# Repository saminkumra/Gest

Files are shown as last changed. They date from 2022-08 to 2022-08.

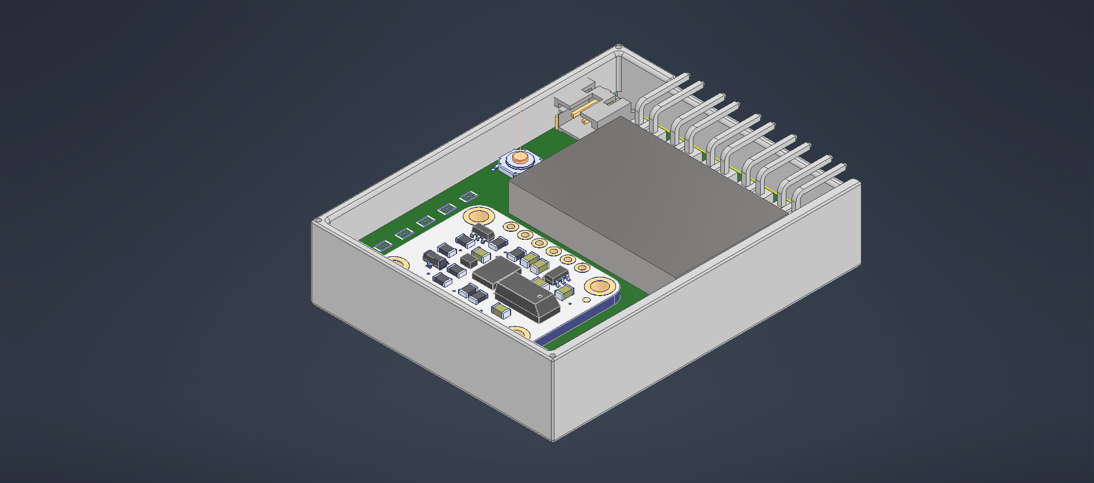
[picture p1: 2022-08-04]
hardware/3D_CAD/enclosure_1.png

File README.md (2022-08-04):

# CE347_Gest
###### By Joshua Feist, Isabelle Johnson, Samin Kumra, Seth May, Haroon Nawaz, Danche Smilkova, and Chris Uustal

### What is Gest? 
The next generation of human-computer interface devices. 

### How does it work? 
While wearing a Gest, you can connect to your laptop and perform different gestures
which then map to basic functions on your computer. 

### Is it open source? 
Yes! That's why all the code is on GitHub. 

### Update Log:
- Added BLE connectivity
	- Requires ESP32 or similar BLE-enabled microcontroller
- Added basic mouse movement support
	- Requires BNO055 sensor

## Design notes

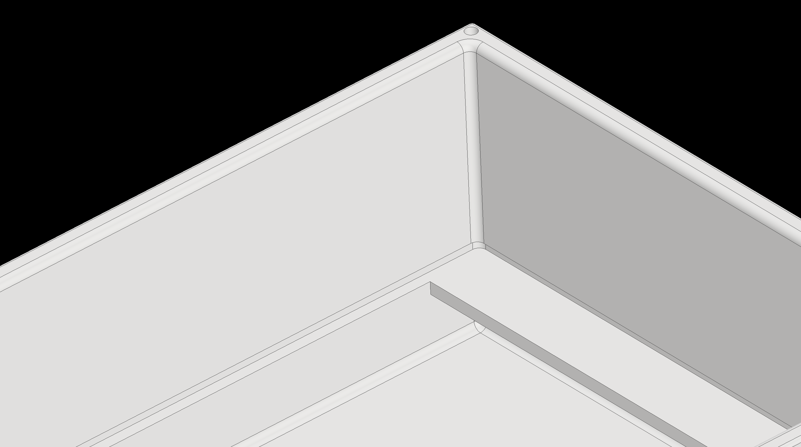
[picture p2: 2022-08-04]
hardware/3D_CAD/enclosure_corner.png

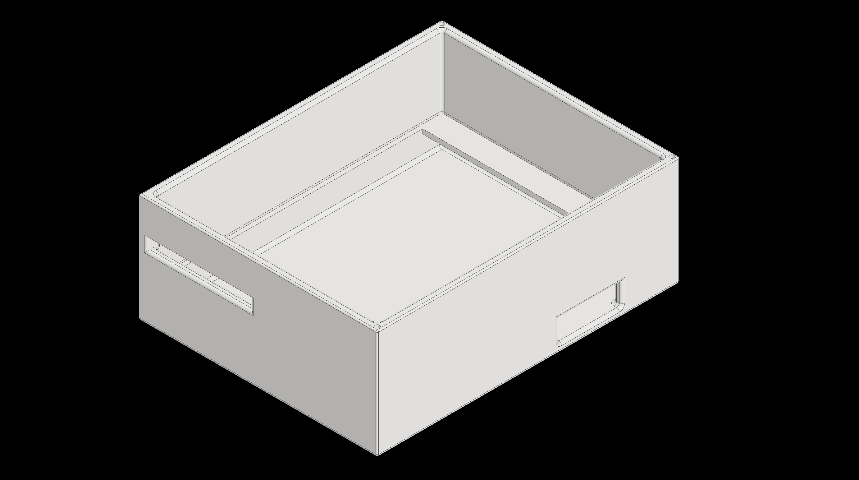
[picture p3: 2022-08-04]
hardware/3D_CAD/enclosure_2.png

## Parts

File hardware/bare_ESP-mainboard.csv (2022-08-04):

Qty | Value | Device | Package | Parts | Description | AVAILABILITY | DESCRIPTION | HEIGHT | LCSC# | MANUFACTURER_NAME | MANUFACTURER_PART_NUMBER | MF | MOUSER_PART_NUMBER | MOUSER_PRICE-STOCK | MP | MPN | OC_FARNELL | OC_NEWARK | PACKAGE | POPULARITY | PRICE | PURCHASE-URL | SPICEPREFIX
1 |  | 22-23-2061 | 22-23-2061 | X1 | .100 (2.54mm) Center Header - 6 Pin" |  |  |  |  |  |  | MOLEX |  |  |  | 22-23-2061 | 1462922 | 27C1933 |  | 6
1 | 100K | RESISTOR_0603_NOOUT | 0603-NO | R12 | Resistors
1 | 100u | CPOL-EUB/3528-21W | B/3528-21W | C4 | POLARIZED CAPACITOR, European symbol |  |  |  |  |  |  |  |  |  |  |  |  |  |  | 4 |  |  | C
3 | 10K | R-EU_R0603 | R0603 | R4, R5, R9 | RESISTOR, European symbol |  |  |  |  |  |  |  |  |  |  |  |  |  |  | 70 |  |  | R
2 | 10u | C-EUC0603 | C0603 | C3, C5 | CAPACITOR, European symbol |  |  |  |  |  |  |  |  |  |  |  |  |  |  | 73 |  |  | C
1 | 12MHz | YSX321SL | SMD3225 | Q1 | SMD Crystal Resonator |  |  |  |  |  |  | Yangxing Tech |  |  | X322512MSB4SI |  |  |  | SMD3225
3 | 15K | FLIPFLOP-RES | 0805-THM | R1, R2, R3 | Flip Flop resistor
2 | 22 | C-EUC0603 | C0603 | C1, C2 | CAPACITOR, European symbol |  |  |  |  |  |  |  |  |  |  |  |  |  |  | 73 |  |  | C
3 | 22-23-2021 | 22-23-2021 | 22-23-2021 | FLEX1, FLEX2, FLEX3 | .100 (2.54mm) Center Header - 2 Pin" |  |  |  |  |  |  | MOLEX |  |  |  | 22-23-2021 | 1462926 | 25C3832 |  | 40
5 | 470 | R-EU_R0603 | R0603 | R6, R7, R8, R10, R11 | RESISTOR, European symbol |  |  |  |  |  |  |  |  |  |  |  |  |  |  | 70 |  |  | R
2 | BC847 | BC847 | SOT23 | T1, T2 | NPN TRANSISTOR |  |  |  |  |  |  |  |  |  |  |  |  |  |  | 5
2 | BLUE | 597-5311-402F | LEDC2012X70N | D1, D2 | LED Uni-Color Green 560nm 2-Pin Chip 0805(2012Metric) Strip | Unavailable | LED Uni-Color Green 560nm 2-Pin Chip 0805_2012Metric_ Tape |  |  |  |  | Dialight |  |  | 597-5311-402F |  |  |  | 0805 Dialight |  | None
1 | CH340G | CH340G | SOIC16 | U2
1 | DIO5508XS8 | DIO5508XS8 | SOIC127P600X170-9N | IC2 | Battery Management 1A Lithium Ion Battery Charger IC |  | Battery Management 1A Lithium Ion Battery Charger IC | 1.7mm |  | DIOO Microcircuits | DIO5508XS8 |  | 453-DIO5508XS8 | https://www.mouser.co.uk/ProductDetail/DIOO-Microcircuits/DIO5508XS8?qs=wUXugUrL1qzPv8nEmpxvyA%3D%3D
1 | DMG3415U | MOSFET-P | SOT23-R | Q3 | P-Channel Mosfet
1 | ESP32-WROOM-32D | ESP32-WROOM-32D | MODULE_ESP32-WROOM-32D | U1 | Bluetooth, WiFi 802.11b/g/n, Bluetooth v4.2 + EDR, Class 1, 2 and 3 Transceiver Module 2.4GHz ~ 2.5GHz Integrated, Trace Surface Mount Check availability | In Stock | Bluetooth, WiFi 802.11b/g/n, Bluetooth v4.2 +EDR, Class 1, 2 and 3 Transceiver Module 2.4GHz ~ 2.5GHz Integrated |  |  |  |  | Espressif Systems |  |  | ESP32-WROOM-32D |  |  |  | Module Espressif Systems |  | None | https://pricing.snapeda.com/search/part/ESP32-WROOM-32D/?ref=eda
3 | GREEN | 597-5311-402F | LEDC2012X70N | D3, D5, D6 | LED Uni-Color Green 560nm 2-Pin Chip 0805(2012Metric) Strip | Unavailable | LED Uni-Color Green 560nm 2-Pin Chip 0805_2012Metric_ Tape |  |  |  |  | Dialight |  |  | 597-5311-402F |  |  |  | 0805 Dialight |  | None
1 | JSTPH | CON_JST_PH_2PIN | JSTPH2 | X2 | JST 2-Pin Right-Angle Connector
1 | MBR120 | DIODE-SCHOTTKYSOD-123 | SOD-123 | D4
1 | TPS78533QWDRBRQ1 | TPS78533QWDRBRQ1 | SON65P300X300X100-9N | IC1 | LDO Voltage Regulators Automotive, 1-A, high-accuracy, adjustable low-dropout (LDO) linear regulator |  | LDO Voltage Regulators Automotive, 1-A, high-accuracy, adjustable low-dropout (LDO) linear regulator | 1mm |  | Texas Instruments | TPS78533QWDRBRQ1 |  | 595-TPS78533QWDRBRQ1 | https://www.mouser.co.uk/ProductDetail/Texas-Instruments/TPS78533QWDRBRQ1?qs=iLbezkQI%252BsiNbdqh2Ko9GQ%3D%3D
2 | TS36CA-0.7 | TS36CA-0.7 | SMD | BTN1, BTN2 | SHOU HAN TS36CA-0.7 |  |  |  | C412365 |  |  | SHOU HAN |  |  | TS36CA-0.7
1 | USB4105_REVA | USB4105_REVA | GCT_USB4105_REVA | J1 | USB Type C Receptacle for USB 2.0 | Unavailable | USB-C (USB TYPE-C) USB 2.0 Receptacle Connector 24 (16+8 Dummy) Position Surface Mount, Right Angle | Through Hole |  |  |  |  | Global Connector Technology |  |  | USB4105 |  |  |  | Package |  | None

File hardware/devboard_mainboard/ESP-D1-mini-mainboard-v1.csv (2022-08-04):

Qty | Value | Device | Package | Parts | Description | DESCRIPTION | DIGI-KEY_PART_NUMBER | HEIGHT | MANUFACTURER_NAME | MANUFACTURER_PART_NUMBER | MF | MOUSER_PART_NUMBER | MOUSER_PRICE-STOCK | MP | MPN | OC_FARNELL | OC_NEWARK | PACKAGE | POPULARITY | PURCHASE-URL | SPICEPREFIX
1 |  | 22-23-2061 | 22-23-2061 | X1 | .100 (2.54mm) Center Header - 6 Pin" |  |  |  |  |  | MOLEX |  |  |  | 22-23-2061 | 1462922 | 27C1933 |  | 6
5 |  | LEDCHIPLED_0805 | CHIPLED_0805 | LED1, LED2, LED3, LED4, LED5 | LED
1 | 100u | CPOL-EUB/3528-21W | B/3528-21W | C4 | POLARIZED CAPACITOR, European symbol |  |  |  |  |  |  |  |  |  |  |  |  |  | 4 |  | C
2 | 10k | R-US_M0805 | M0805 | R9, R12 | RESISTOR, American symbol
1 | 10u | C-EUC0603 | C0603 | C3 | CAPACITOR, European symbol |  |  |  |  |  |  |  |  |  |  |  |  |  | 73 |  | C
3 | 15K | R-US_M0805 | M0805 | R1, R2, R3 | RESISTOR, American symbol
5 | 1k | R-US_M0805 | M0805 | R4, R5, R6, R7, R8 | RESISTOR, American symbol
3 | 22-23-2021 | 22-23-2021 | 22-23-2021 | FLEX1, FLEX2, FLEX3 | .100 (2.54mm) Center Header - 2 Pin" |  |  |  |  |  | MOLEX |  |  |  | 22-23-2021 | 1462926 | 25C3832 |  | 40
1 | 2k | R-US_M0805 | M0805 | R13 | RESISTOR, American symbol
1 | 3k | R-US_M0805 | M0805 | R14 | RESISTOR, American symbol
2 | 470 | R-EU_R0603 | R0603 | R10, R11 | RESISTOR, European symbol |  |  |  |  |  |  |  |  |  |  |  |  |  | 70 |  | R
1 | BUTTON | BUTTON | BUTTON_4_PAD | S1 | Button SPST-NO DigiKey | Tactile Switch SPST-NO Top Actuated Surface Mount | CKN9104TR-ND |  |  |  | C&K |  |  | PTS525SM15SMTR2 LFS |  |  |  | Tactile Switch CK |  | https://pricing.snapeda.com/search/part/PTS525SM15SMTR2 LFS/?ref=eda
1 | DIO5508XS8 | DIO5508XS8 | SOIC127P600X170-9N | IC2 | Battery Management 1A Lithium Ion Battery Charger IC | Battery Management 1A Lithium Ion Battery Charger IC |  | 1.7mm | DIOO Microcircuits | DIO5508XS8 |  | 453-DIO5508XS8 | https://www.mouser.co.uk/ProductDetail/DIOO-Microcircuits/DIO5508XS8?qs=wUXugUrL1qzPv8nEmpxvyA%3D%3D
2 | GREEN | LEDCHIPLED_0805 | CHIPLED_0805 | D5, D6 | LED
1 | JSTPH | CON_JST_PH_2PIN | JSTPH2 | X2 | JST 2-Pin Right-Angle Connector
1 | MH-ET_ESP32_D1_MINI | MH-ET_ESP32_D1_MINI | MH-ET_ESP32_D1_MINI | U$1
1 | TPS78533QWDRBRQ1 | TPS78533QWDRBRQ1 | SON65P300X300X100-9N | IC1 | LDO Voltage Regulators Automotive, 1-A, high-accuracy, adjustable low-dropout (LDO) linear regulator | LDO Voltage Regulators Automotive, 1-A, high-accuracy, adjustable low-dropout (LDO) linear regulator |  | 1mm | Texas Instruments | TPS78533QWDRBRQ1 |  | 595-TPS78533QWDRBRQ1 | https://www.mouser.co.uk/ProductDetail/Texas-Instruments/TPS78533QWDRBRQ1?qs=iLbezkQI%252BsiNbdqh2Ko9GQ%3D%3D

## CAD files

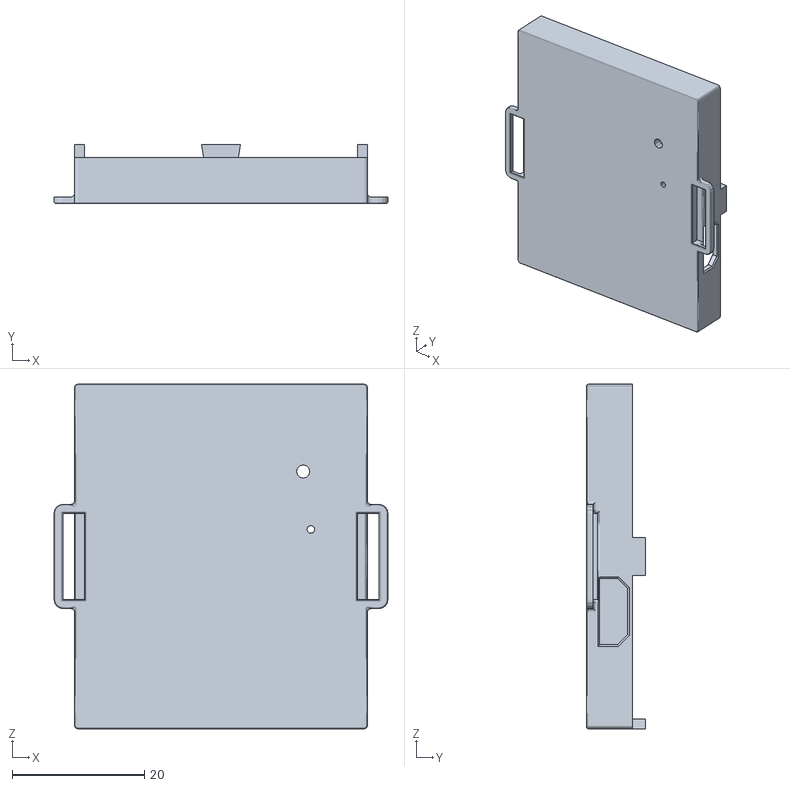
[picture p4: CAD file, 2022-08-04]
hardware/3D_CAD/enclosure5_precise.stl
50.6 x 8.95 x 52.2

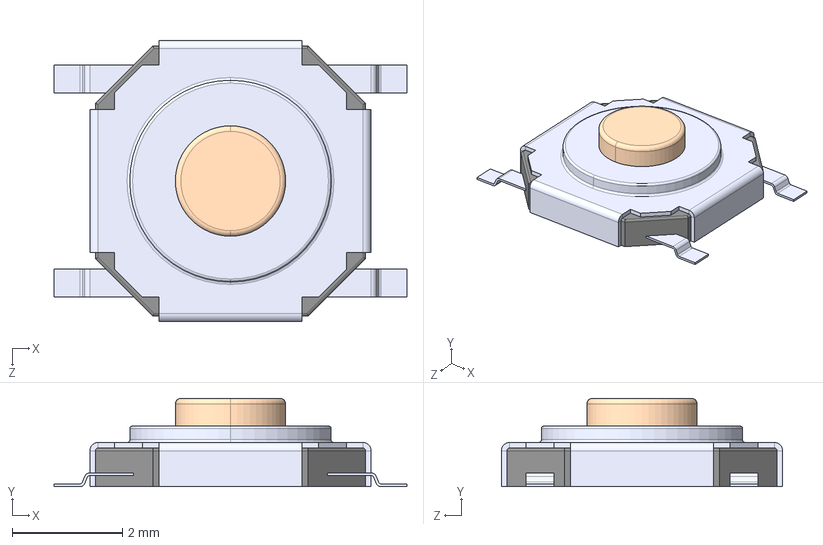
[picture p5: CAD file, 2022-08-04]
hardware/3D_CAD/PTS525SM15SMTR2 LFS.STEP
6.40 x 1.60 x 5.10 mm

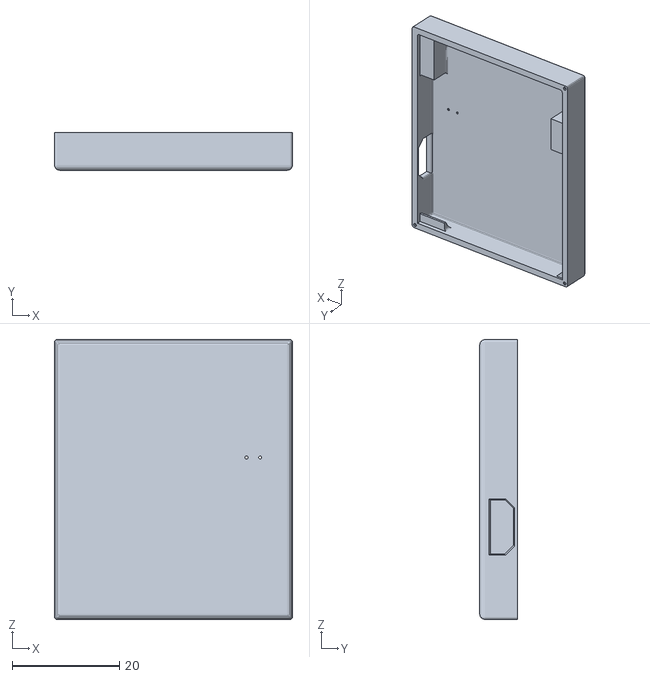
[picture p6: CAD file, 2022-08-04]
hardware/3D_CAD/enclosure3.stl
44.4 x 7.00 x 52.2

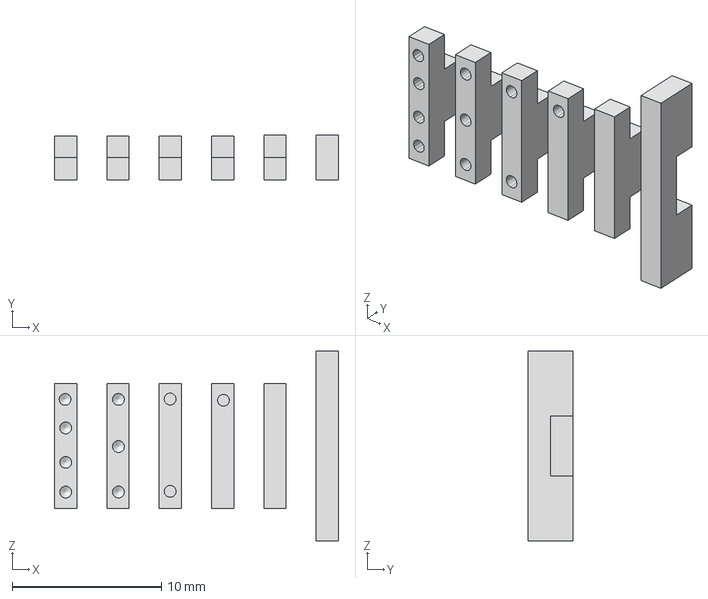
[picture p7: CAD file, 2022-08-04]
hardware/3D_CAD/press_fit_test.3mf
19.0 x 3.00 x 12.7 mm

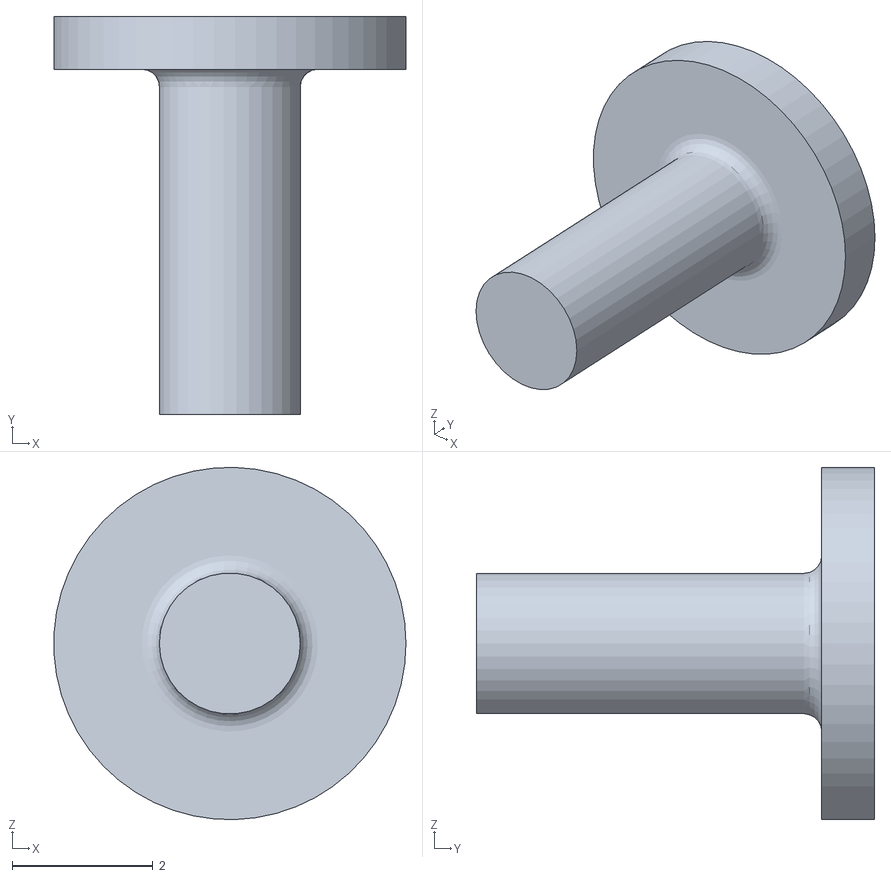
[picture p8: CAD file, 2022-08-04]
hardware/3D_CAD/enclosure3_button.stl
5.00 x 5.65 x 5.00

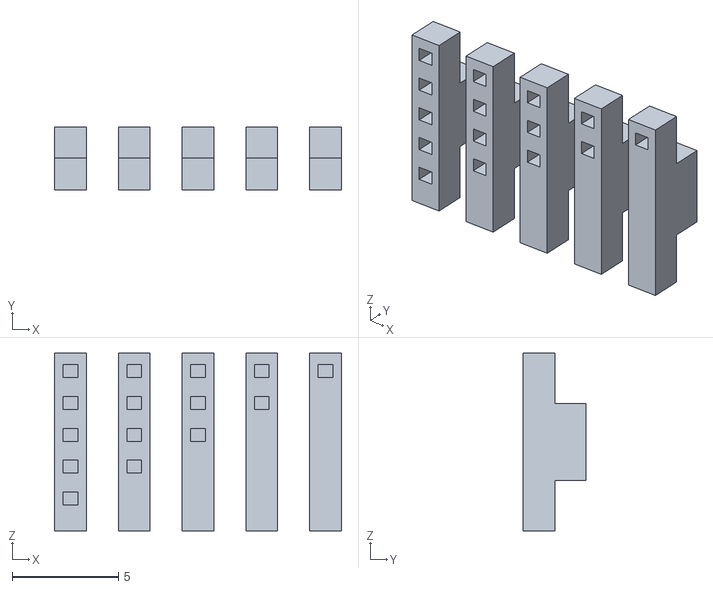
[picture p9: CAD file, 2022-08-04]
hardware/3D_CAD/press_fit_test_2.stl
13.5 x 2.95 x 8.35

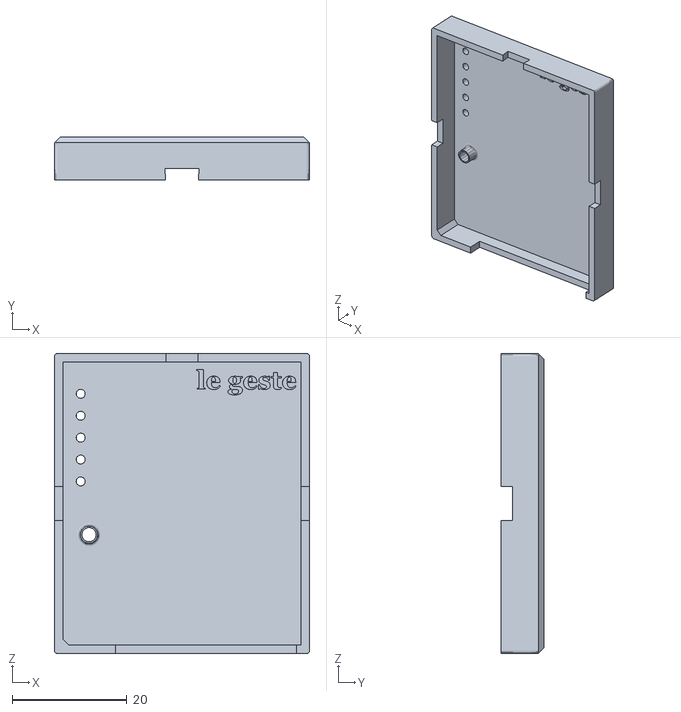
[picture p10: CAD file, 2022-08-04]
hardware/3D_CAD/enclosure5_top_precise.stl
44.4 x 7.50 x 52.2

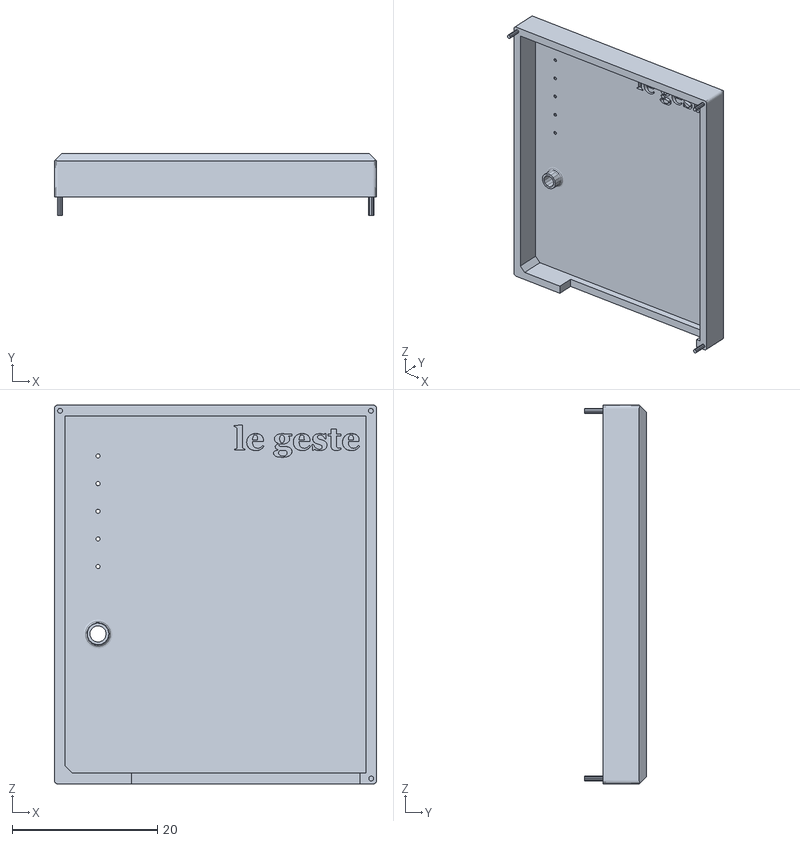
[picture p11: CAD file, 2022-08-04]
hardware/3D_CAD/enclosure3_top.stl
44.4 x 8.50 x 52.2

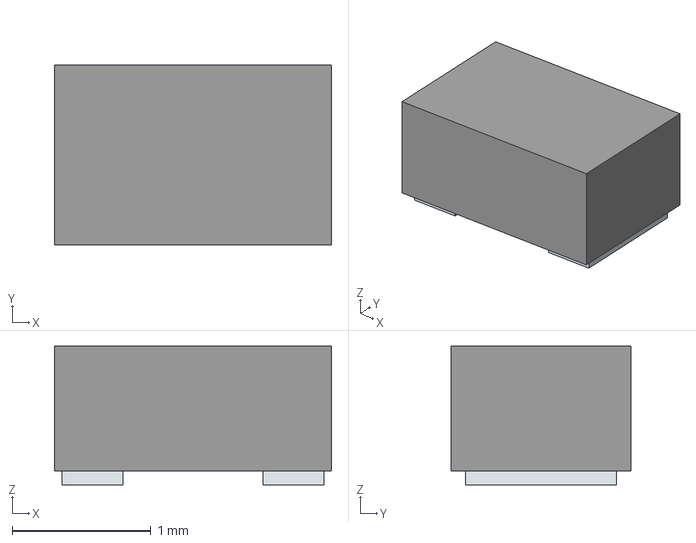
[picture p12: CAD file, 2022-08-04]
hardware/3D_CAD/LG_R971-KN-1-0-20-R18.stp
2.00 x 1.30 x 1.00 mm
Pins

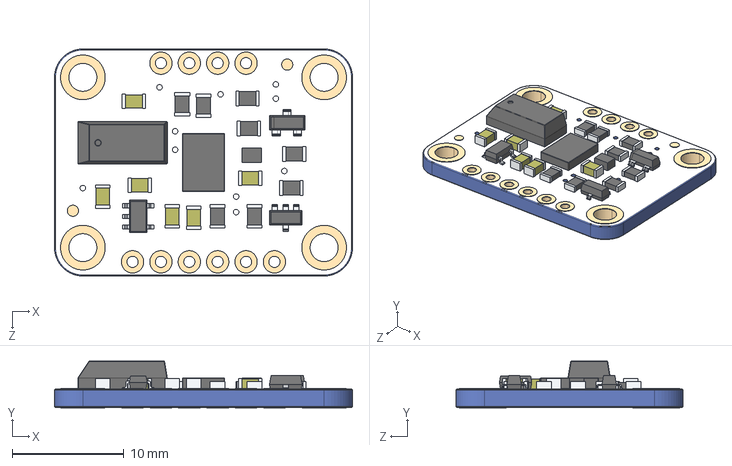
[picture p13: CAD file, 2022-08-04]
hardware/3D_CAD/Adafruit_BNO055_AP214.STEP
26.7 x 4.20 x 20.3 mm

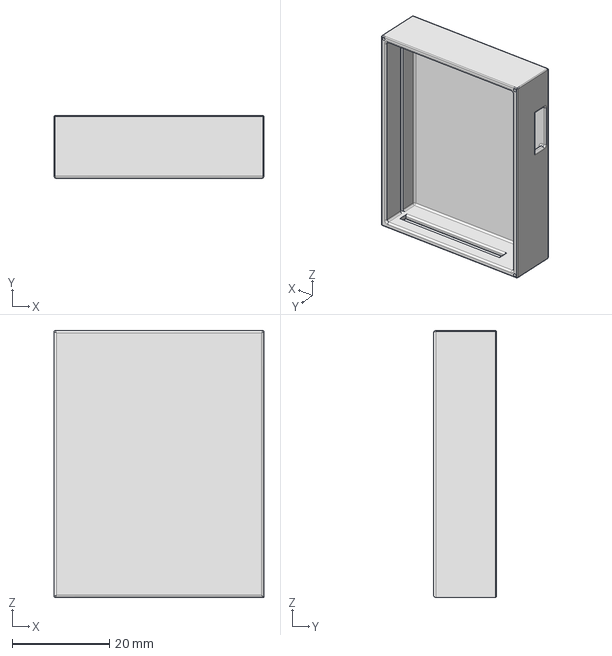
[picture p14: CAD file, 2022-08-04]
hardware/3D_CAD/enclosure2.stp
43.3 x 13.0 x 55.0 mm

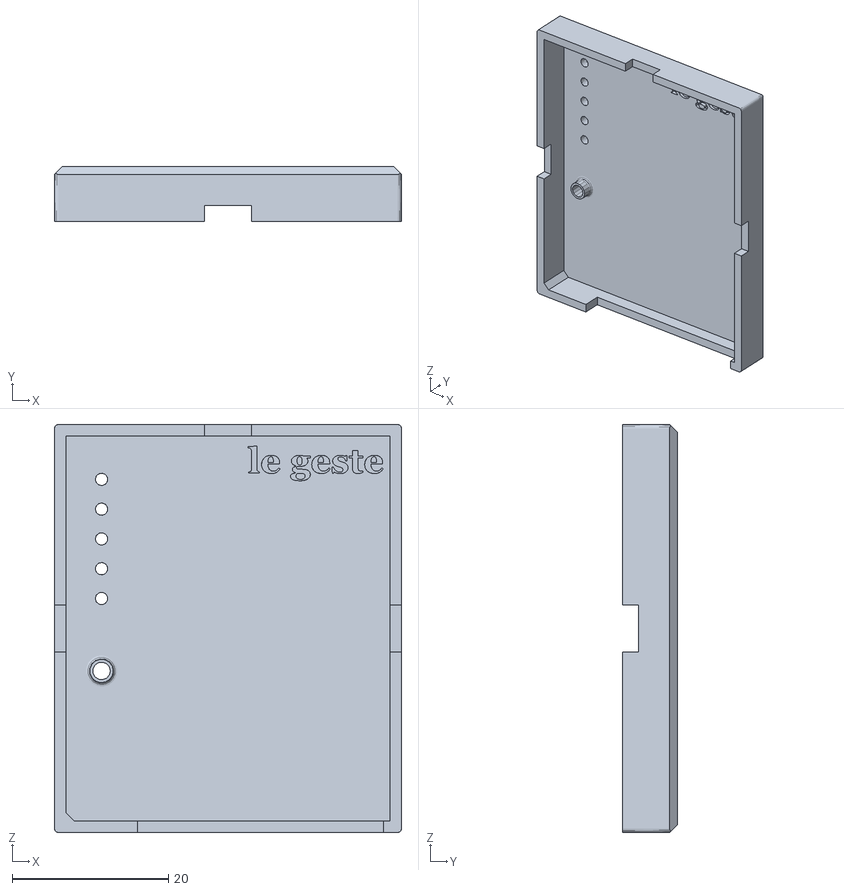
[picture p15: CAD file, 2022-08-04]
hardware/3D_CAD/enclosure4_top.stl
44.4 x 7.00 x 52.2

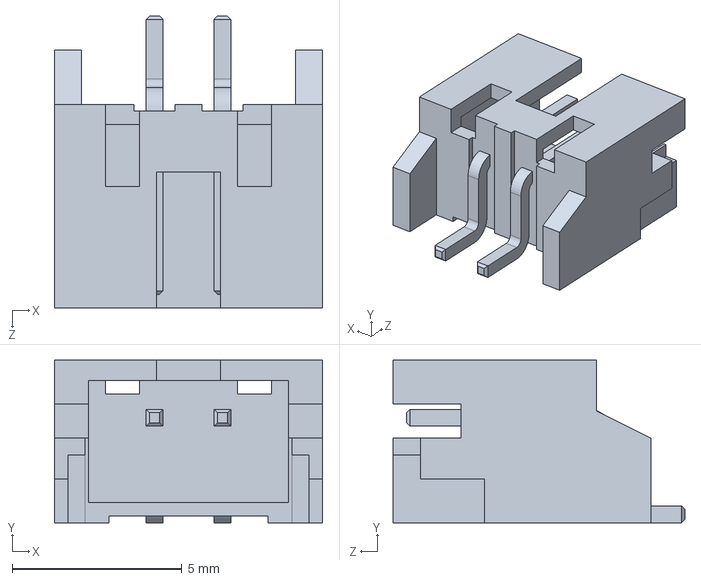
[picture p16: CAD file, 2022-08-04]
hardware/3D_CAD/S2B-PH-SM4-TB.SLDPRT
7.90 x 4.80 x 8.60 mm

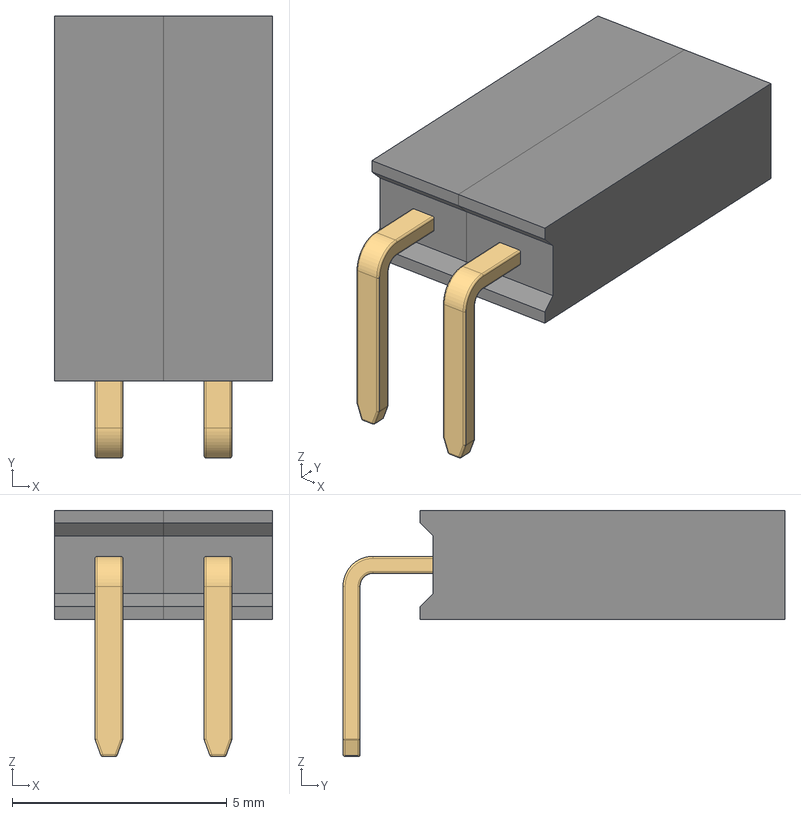
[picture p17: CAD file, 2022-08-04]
hardware/3D_CAD/Female Pin Header 01x02 Right Angle.stp
5.08 x 10.3 x 5.74 mm
Female Pin Header 1x Right Angle x 2

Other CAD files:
hardware/3D_CAD/enclosure4.stl
hardware/3D_CAD/enclosure5.stl
hardware/3D_CAD/enclosure5_top.stl
hardware/3D_CAD/enclosure4_button.stl
hardware/3D_CAD/022032021.stp
hardware/3D_CAD/022052021.stp
hardware/3D_CAD/OldVersions/battery.0004.ipt
hardware/3D_CAD/OldVersions/enclosure.0018.ipt
hardware/3D_CAD/OldVersions/enclosure2.0028.ipt
hardware/3D_CAD/OldVersions/enclosure3.0072.ipt
hardware/3D_CAD/OldVersions/enclosure3_button.0009.ipt
hardware/3D_CAD/OldVersions/enclosure3_top.0030.ipt
hardware/3D_CAD/OldVersions/enclosure4.0103.ipt
hardware/3D_CAD/OldVersions/enclosure4_button.0010.ipt
hardware/3D_CAD/OldVersions/enclosure4_top.0043.ipt
hardware/3D_CAD/OldVersions/enclosure_lid.0014.ipt
hardware/3D_CAD/OldVersions/pcb.0014.ipt
hardware/3D_CAD/OldVersions/pcb_assembled_2.0006.iam
hardware/3D_CAD/OldVersions/pcb_assembled_3.0028.iam
hardware/3D_CAD/OldVersions/pcb_assembled_4.0034.iam
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

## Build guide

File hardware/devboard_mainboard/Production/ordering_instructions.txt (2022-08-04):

panel size, 83x98mm
PCB thickness, 1.6mm
number of layers, 2
soldermask color, Unknown
silkscreen color, White
oz copper, 1oz
finish, HASL lead free
stencils, none
pcs per panel, 4
min trace width, 0.1524mm / 0.0060in
min drill size, 0.3500mm / 0.0138in

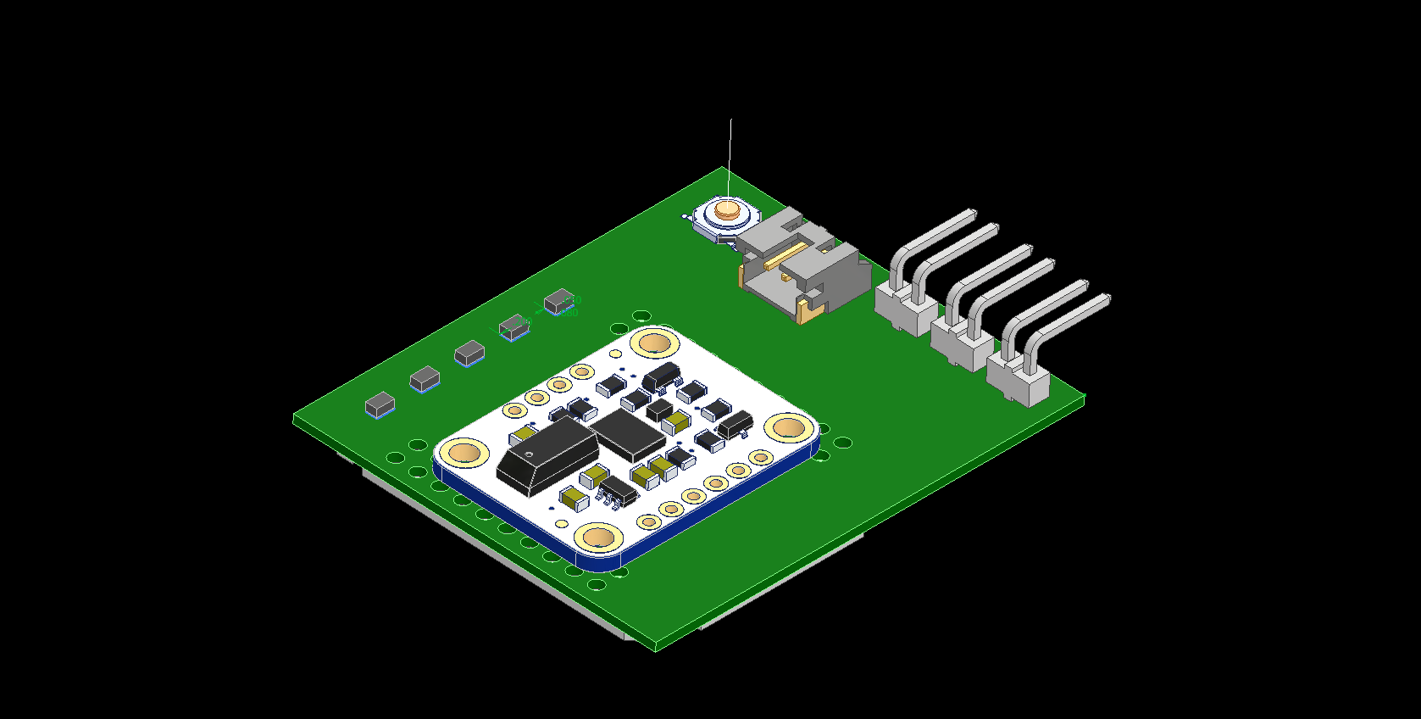
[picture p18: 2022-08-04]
hardware/3D_CAD/assembly_top.png

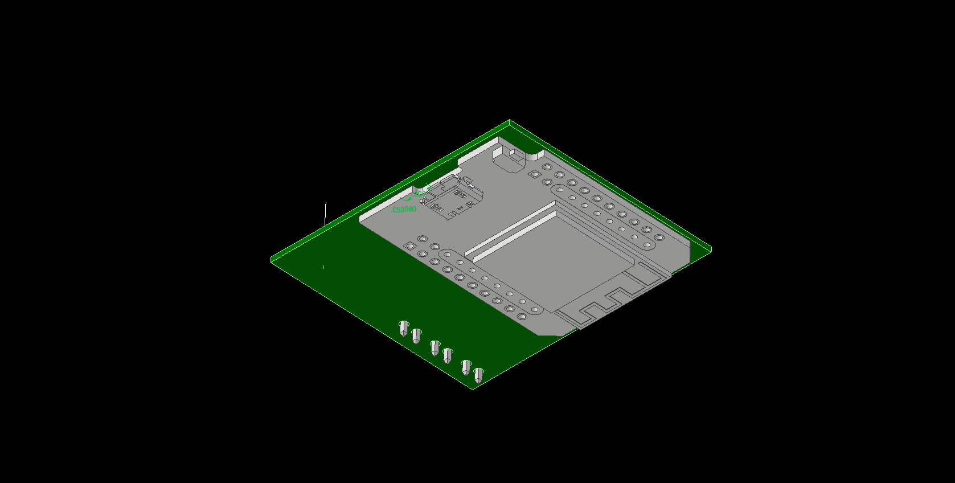
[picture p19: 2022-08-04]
hardware/3D_CAD/assembly_bottom.png

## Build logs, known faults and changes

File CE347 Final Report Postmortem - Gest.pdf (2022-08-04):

### Gest Final Report Postmortem

Joshua Feist | JoshuaFeist2023@u.northwestern.edu
Isabelle Johnson | IsabelleJohnson2023@u.northwestern.edu
Samin Kumra | SaminKumra2022@u.northwestern.edu
Haroon Nawaz | HaroonNawaz2022@u.northwestern.edu
Danche Smilkova | DancheSmilkova2023@u.northwestern.edu
Chris Uustal | ChristopherUustal2023@u.northwestern.edu
Northwestern University | CE347-2 | Spring ‘22

Design Overview
The finalized design of Gest is essentially the same design that was called out in the original design report. That is, it has the Wemos D1 Mini breakout board for the ESP32 at its core, and it utilizes an array of flex sensors and an absolute orientation sensor mounted at the base of the hand to measure linear acceleration as well as finger flexure. In particular, we used the same flex sensors as we originally used in our testing, the Adafruit long (https://www.adafruit.com/product/182) and short (https://www.adafruit.com/product/1070) flex sensors, as well as the same Adafruit BNO055 absolute orientation sensor. (https://learn.adafruit.com/adafruit-bno055-absolute-orientation-sensor) Combined with a 400mAh battery we found on Amazon and some PCB components, these elements were all integrated together onto a custom PCB in a 3D printed enclosure we designed. Below is an image of the full Gest:

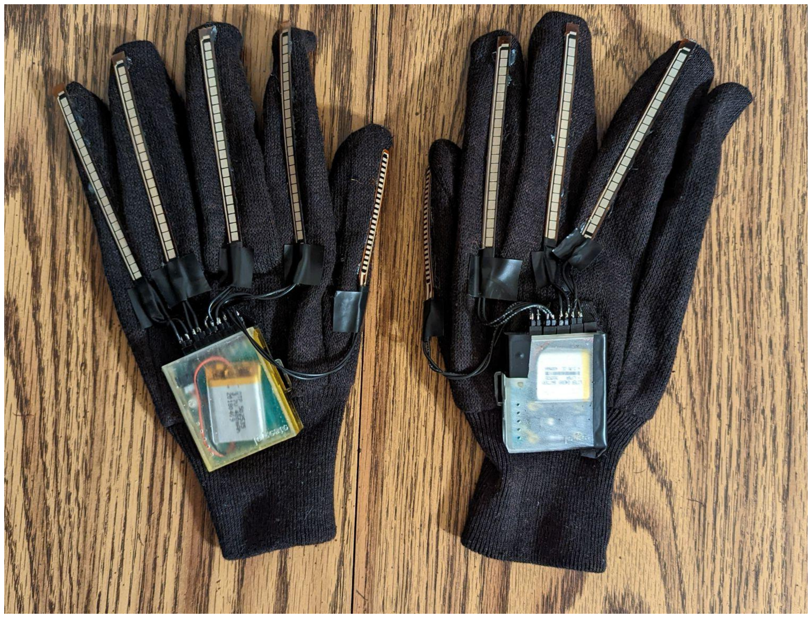
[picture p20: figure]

As is clearly the elephant in the room and what I think is our most impressive accomplishment is that we actually made a full set! We found very early on in the process that achieving the basic deliverables we originally set out to make would be 1) very and easy to achieve and 2) didn’t give us the functionality we wanted to actually recommend using the device. How did we come to this conclusion, you may be asking? Well, using the mouse sucked. After a significant amount of effort was put into trying to smooth and process the data we were getting from the absolute orientation sensor, we came to realize that we weren’t going to get a mouse that anyone was actually going to want to use. There was a similar experience with the zooming functionality we originally called out. While we did get those things working in our initial testing, we couldn’t get them to be good enough that anyone would actually want to use them, so instead we pivoted and focused on making an experience you’d actually want rather than meeting our initial deliverable, and I’m really glad we did!

While you, the reader, will never be able to try our Gest in action, the members of our team have come to an agreement after using the Gest that it’s actually not terrible and can actually be really fun in certain applications. In particular, gaming. As you can see from our hype video here, (https://youtu.be/75vuNPonbbo) we quickly came to realize that (once we had access to the second hand), productivity was probably not the best use case for a device where using the mouse on the desktop sucks, so instead we turned it into a wireless gaming controller and used it to play Minecraft. While there’s definitely a learning curve to getting used to it, none of us found it any worse than switching from a keyboard to a gaming controller or vice versa. If we had known this was the final direction we were going to end up going in from the beginning, we probably could have tuned the interface even more to make it perform really well for certain games.

Going into the hardware just a little bit, the custom PCB ended up being a really good choice for packaging. Since we ended up integrating a rechargeable battery, sensors, a microcontroller, a user interface button, feedback LEDs, and more all into our little enclosure with a height less than 15mm, the custom PCB was essential. The full design files can be found in the Hardware folder on our GitHub. (https://github.com/i-l-johnson/CE347_Gest) From a high level, all the designs were done in Eagle, and the PCBs were manufactured by JLCPCB. We then ordered the components from a mixture of Mouser and DigiKey and assembled them in house. We ended up going through two board revisions because we had some issues with some of the original pins we selected on our microcontroller for some of the flex sensors. To meet the thickness requirements, we had to do a full CAD of the internals of the Gest to make sure it was possible to package it all, and we even had to order a custom ultra-thin PCB (0.6mm vs 1.6mm). You can see the CAD of the full design below:

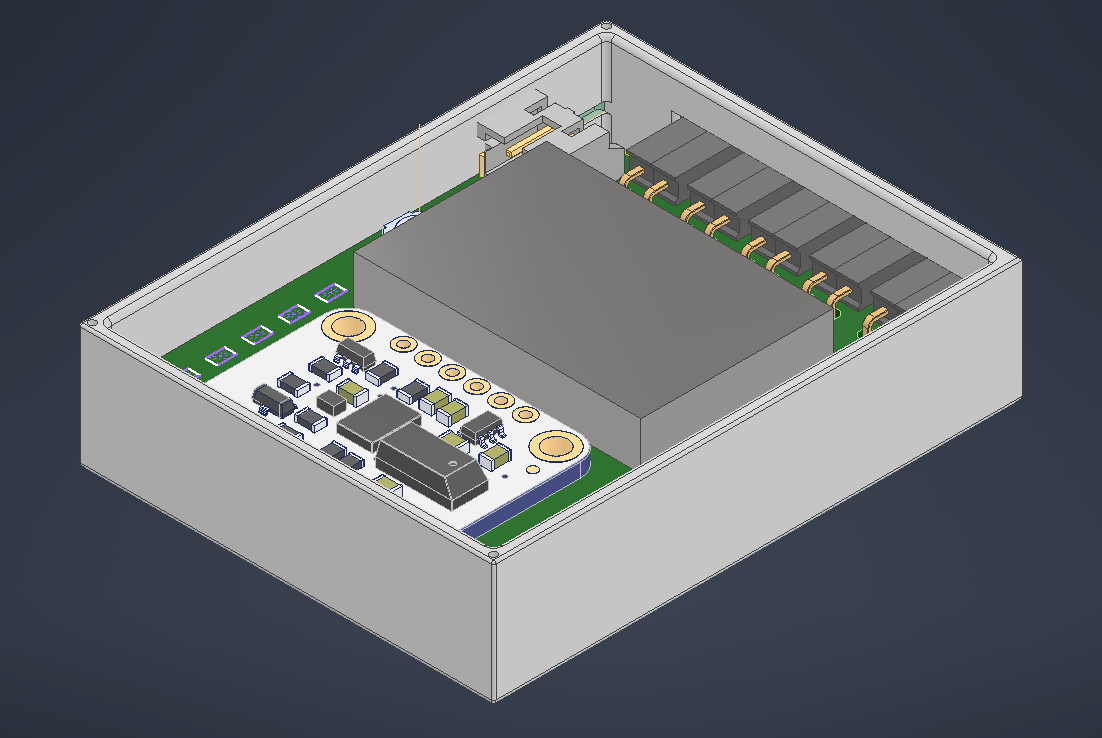
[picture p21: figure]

An element of designing a wearable device that goes under-appreciated really is the thickness. The user generally doesn’t care how large a device is as long as it doesn’t protrude off their body by a lot, and every few mm counts here, so meeting that maximum thickness spec of 15mm called out in the original design report ended up being a difficult challenge to overcome, but the final results were definitely worth the effort. Due to stocking issues on the BNO055 chip, we were not able to order any more than the 2 we originally ordered for prototyping. As such, we chose to only install one on the main-hand which could be used for mouse movement and leave the second one for continued prototyping.

I’m not going to touch on the code too much here, but you can see the full code base on our GitHub here. (https://github.com/i-l-johnson/CE347_Gest) Since we ended up going with two hands, we ended up having two very similar code bases--one for the main hand (right) and one for the off-hand (left). While these code bases shared a lot of similarities in the end, the main differences were that he off-hand didn’t have any of the mouse movement code and was configured predominantly as just a keyboard input while the main-hand was mostly configured to act as a mouse. While we would have liked to make it support both modes, we ended up spending a significant amount of time attempting to design a fully custom BLE protocol for making them communicate to each other and show up to your device as a single peripheral. Sadly, we weren’t able to get that working in time for the demonstration, so you currently have to pair both Gests to your device separately. One thing that ended up being a great addition we forgot to consider initially was calibration--since the gloves fit differently on everyone, that also meant the maximum flex reading from everyone ended up being different. We resolved this by taking a maximum flex reading on startup and again if the user chose to press the recalibration button and using that to define our thresholds for when the user is clicking or not clicking a sensor. While a more advanced approach reading these sensors using an on-board AI, machine learning, or a deep neural network may have better results, this was simple and effective enough that we found it met our needs well.

While the predominant user experience exceeded our expectations, there are a few small things that we probably need to iron out before we’d be comfortable really bringing it to the mainstream. Outside of the physical assembly of the device (which obviously could use some care, but that’s not really our field), the device also currently doesn’t have any way of turning off. That should be a relatively trivial change, but we had some issues with it hanging and not re-pairing to a device when it turned back on, so we left that feature out. This leads to the somewhat annoying result of it just constantly being on then dying while it sets in your backpack after a few hours. While annoying, that’s something we think can be fixed in the future. We already mentioned the small annoyance of having to pair them to your device separately, and this also led to some weird issues where the off-hand would randomly disconnect from our testing laptop far more often than the main-hand, but this could have been from a variety of factors that we weren’t able to isolate. Recharging the device was really easy though since you just plug it in over microUSB and it just figures it all out--it even has an LED to indicate to the user that the battery is charging.

Changes
As mentioned, there ended up being a number of features we originally planned on implementing, while we did get them working, we just couldn’t get them working well enough to actually make a product the user would want to use. Instead, we dynamically pivoted to continue focusing on making a product the user would actually want to use and dropped some of our initially called out functions. In particular, we originally said we were going to implement 3 functions: clicking, mouse movement, and zooming. Since we figured out that, while the mouse movement was functional, it wasn’t particularly enjoyable to use on a desktop environment, we pivoted to mainly focusing on things like typing and gaming. As such, the focus shifted away from the zooming feature, since that isn’t use much at all in those two spheres. Additionally, while we did get a zooming feature working, it fell into a similar camp as the mouse movement where, while it worked technically, we couldn’t get it to a state where it was enjoyable to use. As such, we pivoted instead to add in the features of a full second hand and typing. If we had more experience with user interface design and had a more cohesive design team, we likely could have produced a product which included the zooming feature as a secondary option the user could switch to, but we changed the way our user interacted with the device so many times due to an inexperience in this space that it did not make it into the final product.

Another topic that went completely differently than expected was timelines. We essentially finished all of our initial deliverables weeks before anticipated (which was really good!), but we quickly came to the realization we mentioned before that the features we were actually targeting just weren’t great. Since we were lucky enough to be very ahead on our deliverables, we made the dynamic decision around week 6 to push forward with support of typing, gaming mode, and full two hand support. While this was not reflected in the initial timeline and we have no way of knowing that this would have been the direction we chose to go in, it is something that (had we somehow known to go in this direction) could have allowed us to produce an even better deliverable due to the increased development time which could have been directed towards the user experience.

Since we pivoted our design from a single hand to a two-hand design, our original cost estimates of approximately $115 for the full prototype obviously became invalid since we now required significantly more components. The total cost, including things just the custom PCB and its components as well as all the flex sensors, absolute orientation sensors, and microcontrollers ended up costing somewhere in the range of $300 total, but most of this was funded by the team directly out of pocket. While this significantly exceeds the original cost estimate, the majority of this was due to the cost of flex sensors ($13/each) and the new design now moving from only requiring 3 to requiring 10. We also had a fun learning process of how to accidentally break flex sensors, so we ended up having to replace a few of them before we understood how to properly reinforce them so they didn’t keep breaking on our prototypes. Also, since we pivoted to using an off-the-shelf ESP32 solution instead of integrating the module directly into the board, that added unexpected costs as those are much more expensive than the module itself. Including other factors such as a second revision to the board, more PCB components than expected, and the cost of shipping, the significantly higher cost of the project becomes clear. While these are elements which are easy to highlight in hindsight as oversights from the initial scope of the budget, they are also the costs that come with prototyping and learnings, so it may be recommended in the future to just add a 2x factor on all prototyping costs to account for miscellaneous issues which may arise with the components which were originally selected.

Closing Thoughts
I think we’re all really happy with the deliverables we were able to produce. While Gest definitely doesn’t look exactly how we originally envisioned it looking or do all the things we originally envisioned it doing, it’s actually fun to use and something that (if we have the time) some of us are interested in developing a little more in the future. We’ve already discussed ways that the flex sensors could be more effectively integrated into the hardware of the glove directly, the connection point to the processing unit could be much more robust, and the processing unit itself could be a lot smaller if we pivoted to a full custom PCB with no off-the-shelf development hardware (pending those items coming back in stock). We could get a lot closer to the size of a classic fitness tracker rather than the still somewhat large tile that we currently have, and that, combined with some minor user interface improvements, could make it a genuinely really nice device to use. We might even throw some machine learning onto it and see if we can get even more useful data out of those flex sensors. All in all, we learned a lot, had a great time, and are really proud of the thing we got to make. We’re sad we weren’t able to take it in person and do a live demo with it, because the looks on all of our faces when we put a full assembled Gest on for the first time and starting using it was honestly priceless.

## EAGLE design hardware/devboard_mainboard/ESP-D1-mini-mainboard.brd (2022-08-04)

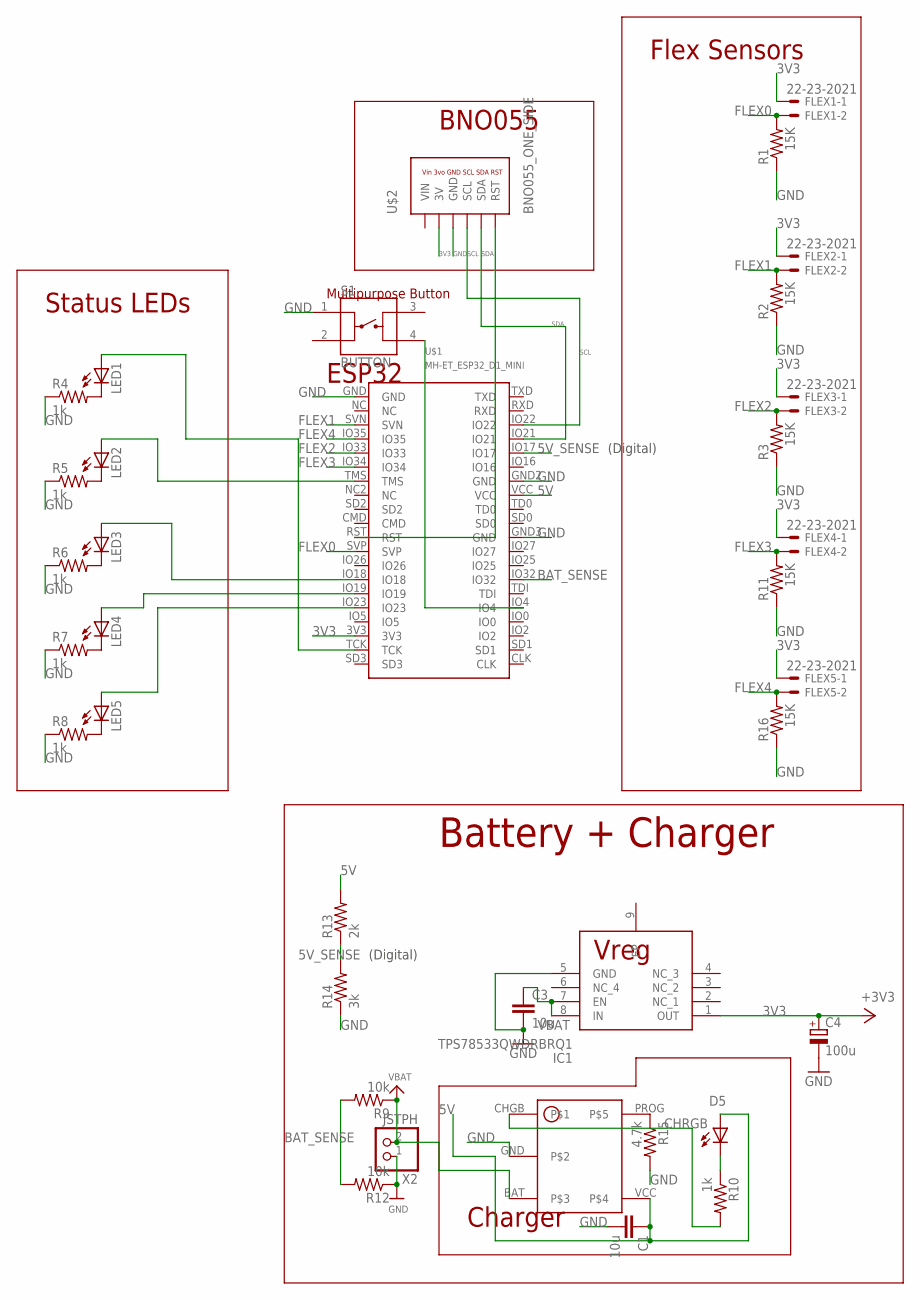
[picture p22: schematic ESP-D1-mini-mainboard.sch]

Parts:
C1, C3: 10u; C0805
C4: 100u; B/3528-21W
D5: GREEN; CHIPLED_0805
FLEX1, FLEX2, FLEX3, FLEX4, FLEX5: 22-23-2021
IC1: TPS78533QWDRBRQ1; SON65P300X300X100-9N
LED1, LED2, LED3, LED4, LED5: LEDCHIPLED_0805; CHIPLED_0805
R1, R2, R3, R11, R16: 15K; M0805
R4, R5, R6, R7, R8, R10: 1k; M0805
R9, R12: 10k; M0805
R13: 2k; M0805
R14: 3k; M0805
R15: 4.7k; M0805
S1: BUTTON; BUTTON_4_PAD
U1: DIO5518BAUK+; SOT23-5L
U$1: MH-ET_ESP32_D1_MINI
U$2: BNO055_ONE_SIDE
X2: JSTPH; JSTPH2

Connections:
3V3: C4.+, FLEX1.1, FLEX2.1, FLEX3.1, FLEX4.1, FLEX5.1, IC1.1 (OUT), U$1.3V3, U$2.3V
5V: C1.1, D5.A, R13.2, U1.VCC, U$1.VCC
5V_SENSE: R13.1, R14.2, U$1.IO17
BAT_SENSE: R9.2, R12.2, U$1.IO32
CHRGB: R10.2, U1.CHGB
FLEX0: FLEX1.2, R1.2, U$1.SVP
FLEX1: FLEX2.2, R2.2, U$1.SVN
FLEX2: FLEX3.2, R3.2, U$1.IO33
FLEX3: FLEX4.2, R11.2, U$1.IO34
FLEX4: FLEX5.2, R16.2, U$1.IO35
GND: C1.2, C3.2, C4.-, IC1.5 (GND), R1.1, R2.1, R3.1, R4.1, R5.1, R6.1, R7.1, R8.1, R11.1, R12.1, R14.1, R15.2, R16.1, S1.1, U1.GND, U$1.GND, U$1.GND2 (GND), U$1.GND3 (GND), U$2.GND, X2.1
unnamed: LED1.C, R4.2
unnamed: LED2.C, R5.2
unnamed: LED3.C, R6.2
unnamed: LED4.C, R7.2
unnamed: LED5.C, R8.2
unnamed: LED1.A, U$1.TCK
unnamed: LED2.A, U$1.TMS
unnamed: S1.4, U$1.IO4
unnamed: LED3.A, U$1.IO18
unnamed: U$1.RST, U$2.RST
unnamed: D5.C, R10.1
unnamed: LED4.A, U$1.IO19
unnamed: LED5.A, U$1.IO23
PROG: R15.1, U1.PROG
SCL: U$1.IO22, U$2.SCL
SDA: U$1.IO21, U$2.SDA
VBAT: C3.1, IC1.7 (EN), IC1.8 (IN), R9.1, U1.BAT, X2.2

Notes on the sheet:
BNO055
Vin 3vo GND SCL SDA RST
Flex Sensors
Multipurpose Button
Charger
ESP32
Vreg
Battery + Charger
Status LEDs
(Digital)

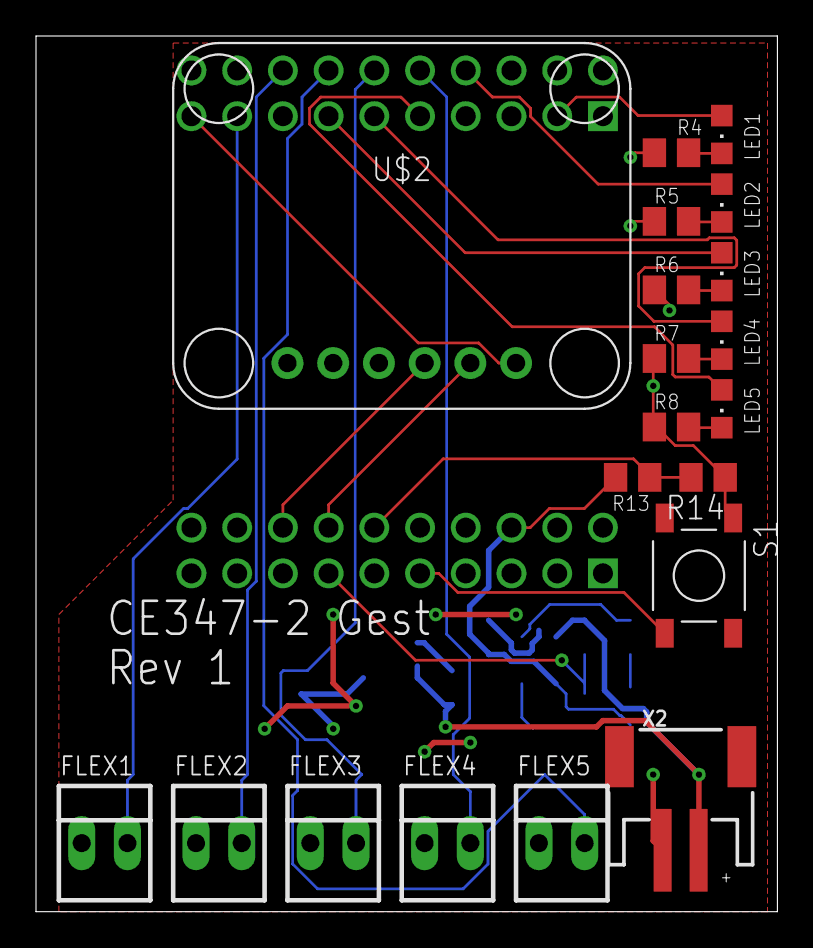
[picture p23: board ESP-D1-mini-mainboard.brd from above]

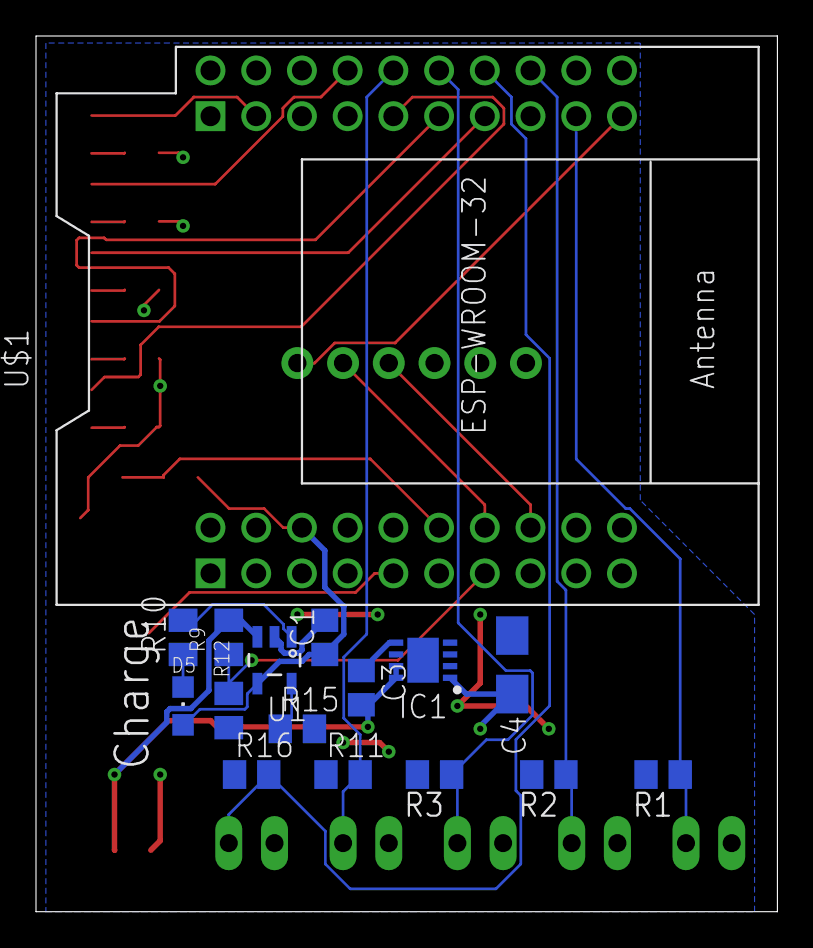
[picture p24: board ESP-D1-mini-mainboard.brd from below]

Board: 2 copper layers, 41.2 x 48.6 mm, 36 parts (16 on the bottom side), 28 nets.

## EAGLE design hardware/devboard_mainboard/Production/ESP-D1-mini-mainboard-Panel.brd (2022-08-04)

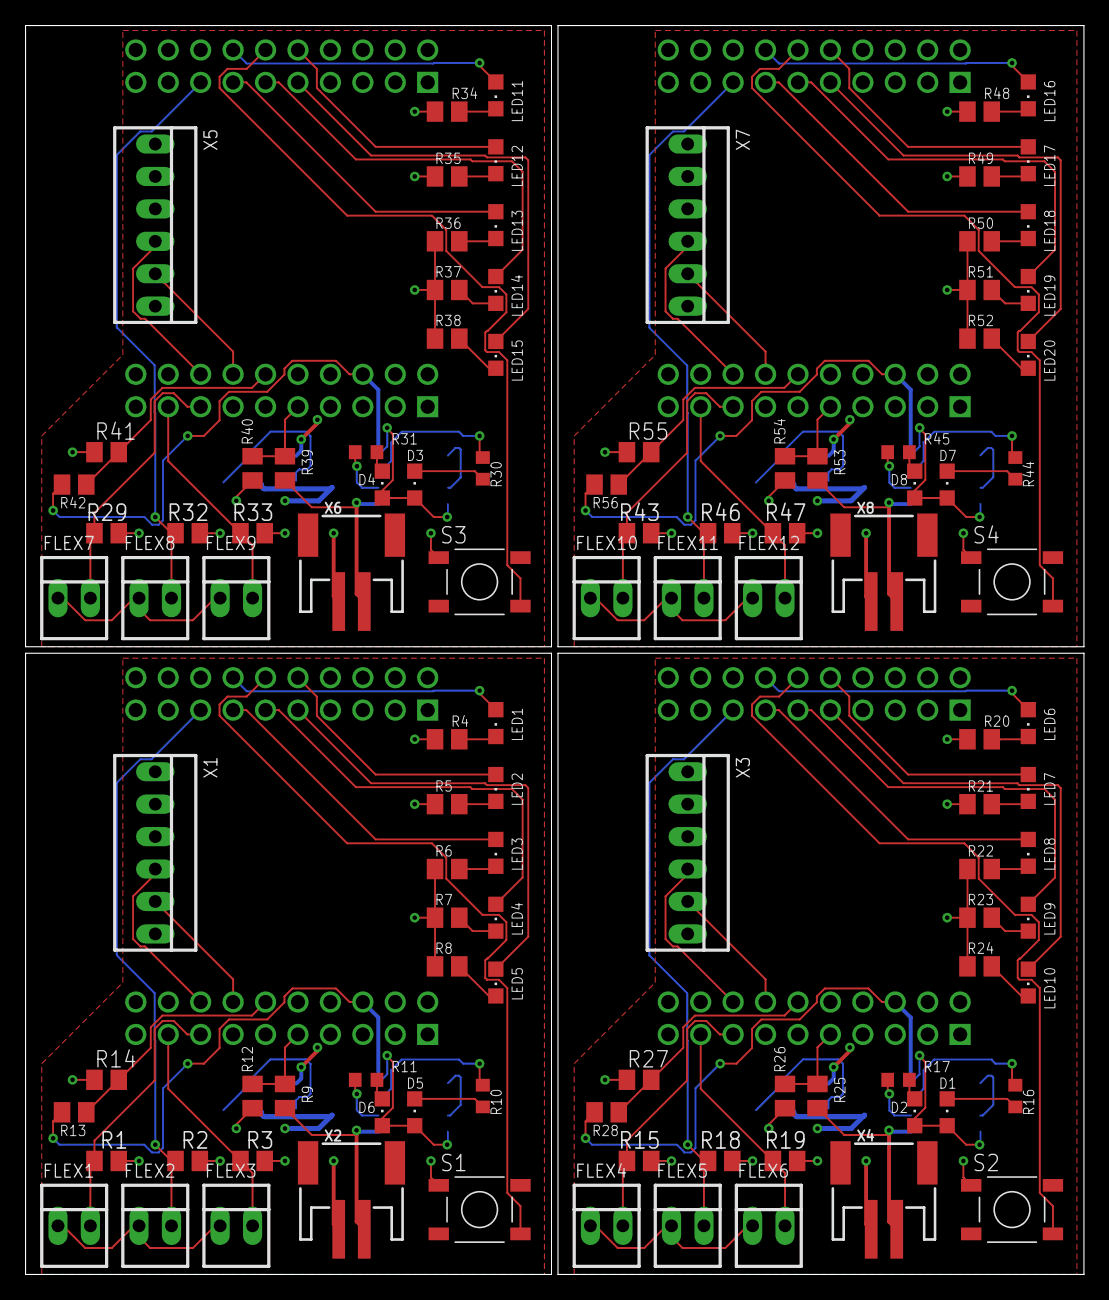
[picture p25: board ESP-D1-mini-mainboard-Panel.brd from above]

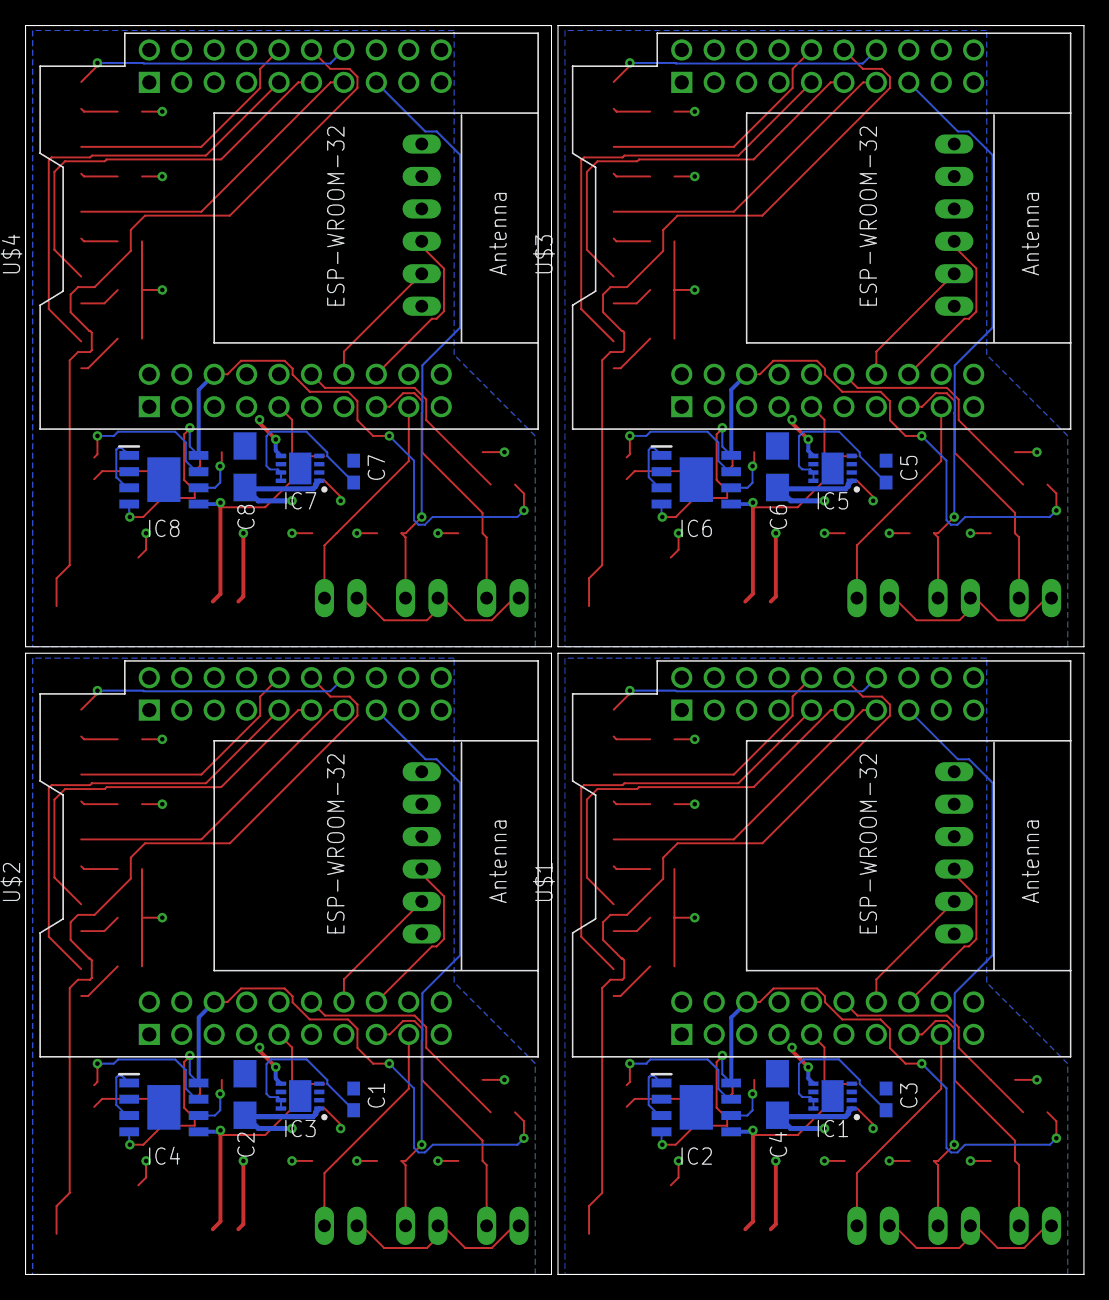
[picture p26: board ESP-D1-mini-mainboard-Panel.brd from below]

Board: 2 copper layers, 82.9 x 97.8 mm, 128 parts (20 on the bottom side), 116 nets.

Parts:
C1, C3, C5, C7: 10u; C0603
C2, C4, C6, C8: 100u; B/3528-21W
D1, D2, D3, D4, D5, D6, D7, D8: GREEN; CHIPLED_0805
FLEX1, FLEX2, FLEX3, FLEX4, FLEX5, FLEX6, FLEX7, FLEX8, FLEX9, FLEX10, FLEX11, FLEX12: 22-23-2021
IC1, IC3, IC5, IC7: TPS78533QWDRBRQ1; SON65P300X300X100-9N
IC2, IC4, IC6, IC8: DIO5508XS8; SOIC127P600X170-9N
LED1, LED2, LED3, LED4, LED5, LED6, LED7, LED8, LED9, LED10, LED11, LED12, LED13, LED14, LED15, LED16, LED17, LED18, LED19, LED20: CHIPLED_0805
R1, R2, R3, R15, R18, R19, R29, R32, R33, R43, R46, R47: 15K; M0805
R4, R5, R6, R7, R8, R20, R21, R22, R23, R24, R34, R35, R36, R37, R38, R48, R49, R50, R51, R52: 1k; M0805
R9, R12, R25, R26, R39, R40, R53, R54: 10k; M0805
R10, R11, R16, R17, R30, R31, R44, R45: 470; R0603
R13, R28, R42, R56: 2k; M0805
R14, R27, R41, R55: 3k; M0805
S1, S2, S3, S4: BUTTON; BUTTON_4_PAD
U$1, U$2, U$3, U$4: MH-ET_ESP32_D1_MINI
X1, X3, X5, X7: 22-23-2061
X2, X4, X6, X8: JSTPH; JSTPH2

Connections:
3V1: FLEX4.1, FLEX5.1, FLEX6.1, U$2.3V3, X3.2
3V2: FLEX7.1, FLEX8.1, FLEX9.1, U$3.3V3, X5.2
3V3: FLEX1.1, FLEX2.1, FLEX3.1, U$1.3V3, X1.2
3V4: FLEX10.1, FLEX11.1, FLEX12.1, U$4.3V3, X7.2
5V: D5.A, D6.A, IC2.4, IC2.8, R13.2, U$1.VCC
5V1: D1.A, D2.A, IC4.4, IC4.8, R28.2, U$2.VCC
5V2: D3.A, D4.A, IC6.4, IC6.8, R42.2, U$3.VCC
5V3: D7.A, D8.A, IC8.4, IC8.8, R56.2, U$4.VCC
5V_SENSE: R13.1, R14.2, U$1.IO17
5V_SENSE1: R27.2, R28.1, U$2.IO17
5V_SENSE2: R41.2, R42.1, U$3.IO17
5V_SENSE3: R55.2, R56.1, U$4.IO17
+3V1: C2.+, IC3.1
+3V2: C6.+, IC5.1
+3V3: C4.+, IC1.1
+3V4: C8.+, IC7.1
BAT_SENSE: R9.2, R12.2, U$1.IO4
BAT_SENSE1: R25.2, R26.2, U$2.IO4
BAT_SENSE2: R39.2, R40.2, U$3.IO4
BAT_SENSE3: R53.2, R54.2, U$4.IO4
GND: C3.2, C4.-, IC1.5, R1.1, R2.1, R3.1, R4.1, R5.1, R6.1, R7.1, R8.1, R12.1, R14.1, S1.1, U$1.GND, U$1.GND2, X1.3, X2.1
GND1: C1.2, C2.-, IC3.5, R15.1, R18.1, R19.1, R20.1, R21.1, R22.1, R23.1, R24.1, R26.1, R27.1, S2.1, U$2.GND, U$2.GND2, X3.3, X4.1
GND2: C5.2, C6.-, IC5.5, R29.1, R32.1, R33.1, R34.1, R35.1, R36.1, R37.1, R38.1, R40.1, R41.1, S3.1, U$3.GND, U$3.GND2, X5.3, X6.1
GND3: C7.2, C8.-, IC7.5, R43.1, R46.1, R47.1, R48.1, R49.1, R50.1, R51.1, R52.1, R54.1, R55.1, S4.1, U$4.GND, U$4.GND2, X7.3, X8.1
unnamed: LED1.C, R4.2
unnamed: LED2.C, R5.2
unnamed: LED3.C, R6.2
unnamed: LED4.C, R7.2
unnamed: LED5.C, R8.2
unnamed: FLEX1.2, R1.2, U$1.IO25
unnamed: FLEX2.2, R2.2, U$1.IO26
unnamed: FLEX3.2, R3.2, U$1.IO27
unnamed: LED1.A, U$1.IO35
unnamed: LED2.A, U$1.IO34
unnamed: S1.4, U$1.IO33
unnamed: LED3.A, U$1.IO18
unnamed: IC2.1, IC2.3
unnamed: D5.C, R10.2
unnamed: D6.C, R11.2
unnamed: IC2.7, R10.1
unnamed: IC2.6, R11.1
unnamed: C3.1, IC1.7, IC1.8
unnamed: LED4.A, U$1.IO19
unnamed: LED5.A, U$1.IO23
unnamed: FLEX4.2, R15.2, U$2.IO25
unnamed: FLEX5.2, R18.2, U$2.IO26
unnamed: FLEX6.2, R19.2, U$2.IO27
unnamed: S2.4, U$2.IO33
unnamed: IC4.1, IC4.3
unnamed: D1.C, R16.2
unnamed: D2.C, R17.2
unnamed: IC4.7, R16.1
unnamed: IC4.6, R17.1
unnamed: C1.1, IC3.7, IC3.8
unnamed: LED6.C, R20.2
unnamed: LED7.C, R21.2
unnamed: LED8.C, R22.2
unnamed: LED9.C, R23.2
unnamed: LED10.C, R24.2
unnamed: LED6.A, U$2.IO35
unnamed: LED7.A, U$2.IO34
unnamed: LED8.A, U$2.IO18
unnamed: LED9.A, U$2.IO19
unnamed: LED10.A, U$2.IO23
unnamed: FLEX7.2, R29.2, U$3.IO25
unnamed: FLEX8.2, R32.2, U$3.IO26
unnamed: FLEX9.2, R33.2, U$3.IO27
unnamed: S3.4, U$3.IO33
unnamed: IC6.1, IC6.3
unnamed: D3.C, R30.2
unnamed: D4.C, R31.2
unnamed: IC6.7, R30.1
unnamed: IC6.6, R31.1
unnamed: C5.1, IC5.7, IC5.8
unnamed: LED11.C, R34.2
unnamed: LED12.C, R35.2
unnamed: LED13.C, R36.2
unnamed: LED14.C, R37.2
unnamed: LED15.C, R38.2
unnamed: LED11.A, U$3.IO35
unnamed: LED12.A, U$3.IO34
unnamed: LED13.A, U$3.IO18
unnamed: LED14.A, U$3.IO19
unnamed: LED15.A, U$3.IO23
unnamed: FLEX10.2, R43.2, U$4.IO25
unnamed: FLEX11.2, R46.2, U$4.IO26
unnamed: FLEX12.2, R47.2, U$4.IO27
unnamed: S4.4, U$4.IO33
unnamed: IC8.1, IC8.3
unnamed: D7.C, R44.2
unnamed: D8.C, R45.2
unnamed: IC8.7, R44.1
unnamed: IC8.6, R45.1
unnamed: C7.1, IC7.7, IC7.8
unnamed: LED16.C, R48.2
unnamed: LED17.C, R49.2
unnamed: LED18.C, R50.2
unnamed: LED19.C, R51.2
unnamed: LED20.C, R52.2
unnamed: LED16.A, U$4.IO35
unnamed: LED17.A, U$4.IO34
unnamed: LED18.A, U$4.IO18
unnamed: LED19.A, U$4.IO19
unnamed: LED20.A, U$4.IO23
SCL: U$1.IO22, X1.4
SCL1: U$2.IO22, X3.4
SCL2: U$3.IO22, X5.4
SCL3: U$4.IO22, X7.4
SDA: U$1.IO21, X1.5
SDA1: U$2.IO21, X3.5
SDA2: U$3.IO21, X5.5
SDA3: U$4.IO21, X7.5
VBAT: IC2.5, R9.1, X2.2
VBAT1: IC4.5, R25.1, X4.2
VBAT2: IC6.5, R39.1, X6.2
VBAT3: IC8.5, R53.1, X8.2

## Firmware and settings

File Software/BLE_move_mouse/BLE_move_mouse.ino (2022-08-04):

/**
 * This example turns the ESP32 into a Bluetooth LE mouse that continuously moves the mouse.
 */
#include "BleMouse.h"
#include <Adafruit_BNO055.h>
#include <utility/imumaths.h>
#include <Adafruit_Sensor.h>
#include <Wire.h>
#define PIN_A 15
#define PIN_B 32
#define PIN_C 14
#define DELAY 100

BleMouse bleMouse;
Adafruit_BNO055 bno = Adafruit_BNO055(-1, 0x28);

float vel_x = 0.0;
float acc_x = 0.0;

struct timer{
  unsigned long ref;
  unsigned long delta;
  void update_ref(){
    ref = millis();
  }
} timer1, timer2;

struct mpu_t{
  float accel_x = 0.0;
  float accel_y = 0.0;
  float accel_z = 0.0;
} mpu1;

struct velocity_t{
  float x = 0.0;
  float y = 0.0;
} v1;

struct filter_t{
  unsigned long ref = 0;
  bool active = false;
  unsigned long timeout = 250;
} x_filter, y_filter;

struct button_t{
  int pin;
  bool prev_state = true;
  bool current_state = true;
  bool rising_edge = false;
  bool falling_edge = false;

  void init(int init_pin){
    pin = init_pin;
    pinMode(pin, INPUT_PULLUP);
  }

  void u(){
    prev_state = current_state;
    current_state = digitalRead(pin);
    
    if(prev_state != current_state){
      if(current_state){
        rising_edge = true;
      } else {
        falling_edge = true;
      }
    } else {
      rising_edge = false;
      falling_edge = false;
    }
  }
  
} button_a, button_b;

float accel_threshold = 0.5;
float accel_scalar = 50.0;

void setup() {
  Serial.begin(115200);

  //Begin BLE device
  Serial.println("Starting BLE");
  bleMouse.begin();

  //Begin BNO055 
  Serial.println("Starting BNO055");
  if(!bno.begin())
  {
    /* There was a problem detecting the BNO055 ... check your connections */
    Serial.print("Ooops, no BNO055 detected ... Check your wiring or I2C ADDR!");
    while(1);
  }

  delay(500);

  bno.setExtCrystalUse(true);

  //Pin Setup
  button_a.init(PIN_A);
  button_b.init(PIN_B);
  
  pinMode(PIN_C, INPUT_PULLUP);

  //Begin Virtual Timers
  Serial.println("Starting Virtual Timers");
  timer1.ref = millis();
  timer1.delta = 5;
  timer2.ref = millis();
  timer2.delta = 10;
  
}

void loop() {
  if(bleMouse.isConnected()) {

    //Accelerometer Virtual Timer
    if(timer1.ref + timer1.delta <= millis()){
      timer1.update_ref();
      
      imu::Vector<3> euler = bno.getVector(Adafruit_BNO055::VECTOR_LINEARACCEL);

      mpu1.accel_x = euler.x();
      mpu1.accel_y = euler.y();

      if(abs(mpu1.accel_x) < accel_threshold){
        if(!x_filter.active) {
          x_filter.active = true;
          x_filter.ref = millis();
        }
      } else {
        x_filter.active = false;
      }

      if(abs(mpu1.accel_y) < accel_threshold){
        if(!y_filter.active) {
          y_filter.active = true;
          y_filter.ref = millis();
        }
      } else {
        y_filter.active = false;
      }

      if(digitalRead(PIN_C) == LOW || (x_filter.active && (x_filter.ref + x_filter.timeout <= millis()))){
        v1.x = 0.0;
      } else {
        v1.x += accel_scalar*mpu1.accel_x * timer1.delta / 1000;
      }

      if(digitalRead(PIN_C) == LOW || (y_filter.active && (y_filter.ref + y_filter.timeout <= millis()))){
        v1.y = 0.0;
      } else {
        v1.y += accel_scalar*mpu1.accel_y * timer1.delta / 1000;
      }

      Serial.printf("Vx: %4.2f ", v1.x);
      Serial.printf("Vy: %4.2f ", v1.y);
      Serial.printf("Ax: %4.2f ", mpu1.accel_x);
      Serial.printf("Ay: %4.2f ", mpu1.accel_y);
      Serial.println("");
      
    }

    //BLE Virtual Timer
    if(timer2.ref + timer2.delta <= millis()){
      timer2.update_ref();

      bleMouse.move(v1.x, v1.y, 0);

      button_a.u();
      button_b.u();
      
      if(button_a.falling_edge){
        bleMouse.click(MOUSE_LEFT);
      }
      if(button_b.falling_edge){
        bleMouse.click(MOUSE_RIGHT);
      }
    }
  }
}

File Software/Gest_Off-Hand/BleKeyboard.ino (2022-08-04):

//BleKeyboard.ino
#include "BleKeyboard.h"

#if defined(USE_NIMBLE)
#include <NimBLEDevice.h>
#include <NimBLEServer.h>
#include <NimBLEUtils.h>
#include <NimBLEHIDDevice.h>
#else
#include <BLEDevice.h>
#include <BLEUtils.h>
#include <BLEServer.h>
#include "BLE2902.h"
#include "BLEHIDDevice.h"
#endif // USE_NIMBLE
#include "HIDTypes.h"
#include <driver/adc.h>
#include "sdkconfig.h"


#if defined(CONFIG_ARDUHAL_ESP_LOG)
  #include "esp32-hal-log.h"
  #define LOG_TAG ""
#else
  #include "esp_log.h"
  static const char* LOG_TAG = "BLEDevice";
#endif


// Report IDs:
#define KEYBOARD_ID 0x01
#define MEDIA_KEYS_ID 0x02

static const uint8_t _hidReportDescriptor[] = {
  USAGE_PAGE(1),      0x01,          // USAGE_PAGE (Generic Desktop Ctrls)
  USAGE(1),           0x06,          // USAGE (Keyboard)
  COLLECTION(1),      0x01,          // COLLECTION (Application)
  // ------------------------------------------------- Keyboard
  REPORT_ID(1),       KEYBOARD_ID,   //   REPORT_ID (1)
  USAGE_PAGE(1),      0x07,          //   USAGE_PAGE (Kbrd/Keypad)
  USAGE_MINIMUM(1),   0xE0,          //   USAGE_MINIMUM (0xE0)
  USAGE_MAXIMUM(1),   0xE7,          //   USAGE_MAXIMUM (0xE7)
  LOGICAL_MINIMUM(1), 0x00,          //   LOGICAL_MINIMUM (0)
  LOGICAL_MAXIMUM(1), 0x01,          //   Logical Maximum (1)
  REPORT_SIZE(1),     0x01,          //   REPORT_SIZE (1)
  REPORT_COUNT(1),    0x08,          //   REPORT_COUNT (8)
  HIDINPUT(1),        0x02,          //   INPUT (Data,Var,Abs,No Wrap,Linear,Preferred State,No Null Position)
  REPORT_COUNT(1),    0x01,          //   REPORT_COUNT (1) ; 1 byte (Reserved)
  REPORT_SIZE(1),     0x08,          //   REPORT_SIZE (8)
  HIDINPUT(1),        0x01,          //   INPUT (Const,Array,Abs,No Wrap,Linear,Preferred State,No Null Position)
  REPORT_COUNT(1),    0x05,          //   REPORT_COUNT (5) ; 5 bits (Num lock, Caps lock, Scroll lock, Compose, Kana)
  REPORT_SIZE(1),     0x01,          //   REPORT_SIZE (1)
  USAGE_PAGE(1),      0x08,          //   USAGE_PAGE (LEDs)
  USAGE_MINIMUM(1),   0x01,          //   USAGE_MINIMUM (0x01) ; Num Lock
  USAGE_MAXIMUM(1),   0x05,          //   USAGE_MAXIMUM (0x05) ; Kana
  HIDOUTPUT(1),       0x02,          //   OUTPUT (Data,Var,Abs,No Wrap,Linear,Preferred State,No Null Position,Non-volatile)
  REPORT_COUNT(1),    0x01,          //   REPORT_COUNT (1) ; 3 bits (Padding)
  REPORT_SIZE(1),     0x03,          //   REPORT_SIZE (3)
  HIDOUTPUT(1),       0x01,          //   OUTPUT (Const,Array,Abs,No Wrap,Linear,Preferred State,No Null Position,Non-volatile)
  REPORT_COUNT(1),    0x06,          //   REPORT_COUNT (6) ; 6 bytes (Keys)
  REPORT_SIZE(1),     0x08,          //   REPORT_SIZE(8)
  LOGICAL_MINIMUM(1), 0x00,          //   LOGICAL_MINIMUM(0)
  LOGICAL_MAXIMUM(1), 0x65,          //   LOGICAL_MAXIMUM(0x65) ; 101 keys
  USAGE_PAGE(1),      0x07,          //   USAGE_PAGE (Kbrd/Keypad)
  USAGE_MINIMUM(1),   0x00,          //   USAGE_MINIMUM (0)
  USAGE_MAXIMUM(1),   0x65,          //   USAGE_MAXIMUM (0x65)
  HIDINPUT(1),        0x00,          //   INPUT (Data,Array,Abs,No Wrap,Linear,Preferred State,No Null Position)
  END_COLLECTION(0),                 // END_COLLECTION
  // ------------------------------------------------- Media Keys
  USAGE_PAGE(1),      0x0C,          // USAGE_PAGE (Consumer)
  USAGE(1),           0x01,          // USAGE (Consumer Control)
  COLLECTION(1),      0x01,          // COLLECTION (Application)
  REPORT_ID(1),       MEDIA_KEYS_ID, //   REPORT_ID (3)
  USAGE_PAGE(1),      0x0C,          //   USAGE_PAGE (Consumer)
  LOGICAL_MINIMUM(1), 0x00,          //   LOGICAL_MINIMUM (0)
  LOGICAL_MAXIMUM(1), 0x01,          //   LOGICAL_MAXIMUM (1)
  REPORT_SIZE(1),     0x01,          //   REPORT_SIZE (1)
  REPORT_COUNT(1),    0x10,          //   REPORT_COUNT (16)
  USAGE(1),           0xB5,          //   USAGE (Scan Next Track)     ; bit 0: 1
  USAGE(1),           0xB6,          //   USAGE (Scan Previous Track) ; bit 1: 2
  USAGE(1),           0xB7,          //   USAGE (Stop)                ; bit 2: 4
  USAGE(1),           0xCD,          //   USAGE (Play/Pause)          ; bit 3: 8
  USAGE(1),           0xE2,          //   USAGE (Mute)                ; bit 4: 16
  USAGE(1),           0xE9,          //   USAGE (Volume Increment)    ; bit 5: 32
  USAGE(1),           0xEA,          //   USAGE (Volume Decrement)    ; bit 6: 64
  USAGE(2),           0x23, 0x02,    //   Usage (WWW Home)            ; bit 7: 128
  USAGE(2),           0x94, 0x01,    //   Usage (My Computer) ; bit 0: 1
  USAGE(2),           0x92, 0x01,    //   Usage (Calculator)  ; bit 1: 2
  USAGE(2),           0x2A, 0x02,    //   Usage (WWW fav)     ; bit 2: 4
  USAGE(2),           0x21, 0x02,    //   Usage (WWW search)  ; bit 3: 8
  USAGE(2),           0x26, 0x02,    //   Usage (WWW stop)    ; bit 4: 16
  USAGE(2),           0x24, 0x02,    //   Usage (WWW back)    ; bit 5: 32
  USAGE(2),           0x83, 0x01,    //   Usage (Media sel)   ; bit 6: 64
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

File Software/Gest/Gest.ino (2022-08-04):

/*********************************
 * 
 * Gest - Main
 * Chris | Isabelle | Samin
 * Northwestern CE347 2022
 * 
 * REQUIRED INCLUDE LIBRARIES FOR COMPILE: 
 * Adafruit_Sensor.h
 * Adafruit_BNO055.h
 * 
 * TARGET BOARD:
 * WEMOS D1 MINI ESP32
 * If you do not target this board, all the pin defs will break!
 * 
 ********************************/

 #include "sensors.h"
 #include "timer.h"
 #include "config.h"
 #include "BleHID.h"
 #include "battery.h"
 #include "calibration.h"
 #include "button.h"

unsigned long calibration_mode = 10000;

void setup() {
  #ifdef SERIAL_DEBUG
    Serial.begin(SERIAL_SPEED);
  #endif
  flexInit();
  accelInit();
  bleInit();
  batteryInit();
  button_setup();
  
  allTimersInit();
  
}


void loop() {
  
  if (!button_pressed()){
    flex0_max = 0, flex1_max = 0, flex2_max = 0, flex3_max = 0, flex4_max = 0;
    unsigned long ref = millis();
    calibration_mode = ref + 10000;
  }
  if (millis() < calibration_mode) {
    calibration_setup();
    Serial.printf("new_flex0: %d,\t new_flex1: %d,\t new_flex2: %d,\t new_flex3: %d,\t new_flex4: %d\n", flex0_max, flex1_max, flex2_max, flex3_max, flex4_max);
  }
  if (millis() > calibration_mode) {
    if(locateTimer(&head, 1)->timer->bump()){
      flexTask();
    }
  
    if(locateTimer(&head, 2)->timer->bump()){
      accelTask();
    }
  
    if(locateTimer(&head, 3)->timer->bump()){
      bleTask();
    }
  
    if(locateTimer(&head, 4)->timer->bump()){
      batteryTask();
    }
  }
}

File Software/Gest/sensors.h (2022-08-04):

//sensors.h
#ifndef SENSORS_H
#define SENSORS_H

/* ~~~~~~~~~~ INCLUDES ~~~~~~~~~~ */
/***** GENERAL *****/
#include "config.h"
#include "hardware_defs.h"

/***** BNO055 *****/
#include <Wire.h>
#include <Adafruit_Sensor.h>
#include <Adafruit_BNO055.h>
#include <utility/imumaths.h>

/* ~~~~~~~~~~ DEFINES ~~~~~~~~~~ */
/***** FLEX *****/
#define FLEX0_PIN FLEX0
#define FLEX1_PIN FLEX1
#define FLEX2_PIN FLEX2
#define FLEX3_PIN FLEX3
#define FLEX4_PIN FLEX4
#define FLEX_QTY 5

/* ~~~~~~~~~~ GLOBALS ~~~~~~~~~~ */
Adafruit_BNO055 bno = Adafruit_BNO055(-1, 0x28);
int flex0_max, flex1_max, flex2_max, flex3_max, flex4_max;

/* ~~~~~~~~~~ STRUCTS ~~~~~~~~~~ */
/***** Flex *****/
struct flex_t{
  //Analog pin the flex sensor is connected to
  int pin = 0;
  //Number of ADC counts returned from flex sensor 
  int adcVal = 0;
  //Angle of flex on the flex sensor
  int flexAngle = 0;
  //Is a flex sensor connected at startup 
  int initPass = 0;

  //ADC count lower functional bound (12-bit ADC)
  const int adcLow = 2700;
  //ADC count upper functional bound (12-bit ADC)
  const int adcHigh = 1900;
  //Angle lower functional bound
  const int angleLow = 0; 
  //Angle upper functional bound
  const int angleHigh = 180;

  //Measure the number of ADC counts and put it in adcVal
  int measureAnalogPin(){
    adcVal = analogRead(pin);
    return adcVal;
  }

  //Measure the ADC pin, map it to an angle, and put it in flexAngle
  int measureFlex(){
    flexAngle = map(measureAnalogPin(), adcLow, adcHigh, angleLow, angleHigh);
    return flexAngle;
  }

   //Connect flex sensor object to pin 'input' and config as input
  void init(int input){
    pin = input;
    pinMode(pin, INPUT_PULLDOWN);
    if(measureAnalogPin() < (adcHigh * 1.2) && measureAnalogPin() > (adcLow * 0.8)){
      initPass = 1;
      #ifdef SERIAL_DEBUG
        Serial.println("Flex sensor detected!");
      #endif
    } else {
      #ifdef SERIAL_DEBUG
        Serial.println("Flex sensor not detected");
      #endif
    }
  }
  
} flex0, flex1, flex2, flex3, flex4;

/***** BNO055 *****/
struct lin_accel_t{
  float x = 0.0;
  float y = 0.0;
  float z = 0.0;
};

struct accel_t{
  //Does the BNO055 initialize successfully? 0 = NO, 1 = YES
  int initPass = 0;
  //Linear acceleration object
  lin_accel_t linearAccel;

  //Function for sampling the linear acceleration 
  void measureLinearAccel(){
    imu::Vector<3> euler = bno.getVector(Adafruit_BNO055::VECTOR_LINEARACCEL);
    linearAccel.x = euler.x();
    linearAccel.y = euler.y();
    linearAccel.z = euler.z();
  }
  
} bno055;

/* ~~~~~~~~~~ PROTOTYPES ~~~~~~~~~~ */
/***** Flex *****/
void flexInit();
void flexTask();

/***** BNO055 *****/
void accelInit();
void accelTask();

#endif

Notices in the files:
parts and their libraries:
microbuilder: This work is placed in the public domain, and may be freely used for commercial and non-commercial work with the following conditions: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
